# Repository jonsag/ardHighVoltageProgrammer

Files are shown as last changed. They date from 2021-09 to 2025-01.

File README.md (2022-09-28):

# ardHighVoltageProgrammer

## Links

[https://mightyohm.com/blog/products/hv-rescue-shield-2-x/](https://mightyohm.com/blog/products/hv-rescue-shield-2-x/)  

[https://www.instructables.com/HV-Rescue-Simple/](https://www.instructables.com/HV-Rescue-Simple/)  
[https://mightyohm.com/blog/2008/09/arduino-based-avr-high-voltage-programmer/](https://mightyohm.com/blog/2008/09/arduino-based-avr-high-voltage-programmer/)  
[https://microtherion.github.io/ScratchMonkey/HVPP.html](https://microtherion.github.io/ScratchMonkey/HVPP.html)  
[https://www.instructables.com/AVR-High-voltage-programming-Fuses-rescue/](https://www.instructables.com/AVR-High-voltage-programming-Fuses-rescue/)  
[http://denki.world3.net/avr_rescue.html](http://denki.world3.net/avr_rescue.html)  

[https://www.gmsystems.com/switching-reg-calculator-for-mc-34063-or-mc33063.html](https://www.gmsystems.com/switching-reg-calculator-for-mc-34063-or-mc33063.html)

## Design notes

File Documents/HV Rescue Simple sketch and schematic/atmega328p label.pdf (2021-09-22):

328$Arduino$pinout !$$$$A5

RX$A4
TX A3
2$$$$A2
3$$$$A1 4 $$$A0

V$$$$$$G
G$ARF
X1$AV
X2$13
5$$$$12
6$$$$11
7$$$$10
8$$$$$$9

328$pin$numbers !$$$$28

2$$$$27$
3$$$$26
4$$$$25
5$$$$24
6$$$$23
7$$$$22
8$$$$21
9$$$$20
10$$19
11$$18
12$$17
13$$16
14$$15

328$HV$pinout !$$$$

$$$$$
RDY$$$$
OE$BS

2
WR$$$7
BS1$$$$6
V$$$$$$$G
G$$$$ XTL1$$V

$$$$$$$$$$

5
XA0$$4
XA1$$3
PAG$$2 0$$$$$$$$1

328$HV$pinout$fat !$$$$$$$$$$$$$$$NC

$$$$$
RDY$$$$
OE$$$$$$$$$$BS

2
WR$$$$$$$$$$$$$7
BS1$$$$$$$$$$$$6
V$$$$$$$$$$$$$$$$$G
G$$$$
XTL1$$$$$$$$$$V
$$$$$$$$$$$$$$$$$$$$

5
XA0$$$$$$$$$$$$4
XA1$$$$$$$$$$$$3
PAG$$$$$$$$$$$$2
0$$$$$$$$$$$$$$$$$$1

328$ISP$target$pinout !$$$$NC

$$
$$
$$
$$
$$
V$$$$$$G
G$$
XTL AV
$$$SCK13

$$MISO12
$$MOSI11
$$
NC

328$ISP$target$pinout$fat !$$$$$$$$$$$$$$$$$$$$$NC

$$
$$
$$
$$
$$
V$$$$$$$$$$$$$$$$$$$$$$$G
G$$
XTL$$$$$$$$$$$$$$$$AV
$$$$$$$$$$$$$$$$$SCK13
$$$$$$$$$$$$$$MISO12
$$$$$$$$$$$$$MOSI11
$$
NC$$$$$$$$$$$$$$$$$NC$$$$$$$$$$$$$$$$$

HV$resistor$row$label

RDY
OE
WR
XTL1
BS2
BS1
XA0
XA1

## PAG 76543210

Nano$Arduino$pinout

13$$ $$$$$$$12
3V3$$$$$$$11$
ARF$$$$$$$10
A0$$$$$$$$$$$$9
A1$$$$$$$$$$$$8
A2$$$$$$$$$$$$7
A3$$$$$$$$$$$$6
A4$$$$$$$$$$$$5
A5$$$$$$$$$$$$4
A6$$$$$$$$$$$$3
A7$$$$$$$$$$$$2
VCC$$$GND
RST$$$$RST
GND$$$$$RX
VIN$$$$$$$TX

Nano$HV$programmer$
pinout

RDY$$

Vsup
$$$$$$$$$$$$$$OE
$$$$$$$$$$$$$WR
12VG$ BS2$$$
0$$$$$$$$$$XA0
BS1$$$$$$$$$$

7
XTL1$$$$$$$

6
XA1$$$$$$$$$

5
PAGEL$$$

4
$$$$$$$$$$$$$$$$$

3
$$$$$$$$$$$$$$$$$

2
VCC$$$GND

GND$$$$$$$$
VIN$$$$$$$$$$1

Nano$HV$programmer$ pinout$fat

RDY$$$$$$$$Vsup
$$$$$$$$$$$$$$$$$$$$OE
$$$$$$$$$$$$$$$$$$$WR
12VG$$$$$$$$BS2$$$
0$$$$$$$$$$$$$$$$XA0
BS1$$$$$$$$$$$$$$$$7
XTL1$$$$$$$$$$$$$6
XA1$$$$$$$$$$$$$$$5
PAGEL$$$$$$$$$$4
$$$$$$$$$$$$$$$$$$$$$$$

3
$$$$$$$$$$$$$$$$$$$$$$$

2
VCC$$$$$$$$$GND

GND$$$$$$$$$$$$$$
VIN$$$$$$$$$$$$$$$$1

Nano$ISP$programmer
pinout

13SCK$MISO12
3V3 MOSI11
ARF$$$$$

R10
A0$$$$$$$XTL

9
A1$$$$$$$$$$$$8
A2$$$$$$$$$$$$7
A3$$$$$$$$$$$$6
A4$$$$$$$$$$$$5
A5$$$$$$$$$$$$4
A6$$$$$$$$$$$$3
A7$$$$$$$$$$$$2
VCC$$$$$$$$$G
RST$$$$RST
GND$$$$$RX
VIN$$$$$$$TX

Nano$ISP$programmer
pinout$fat

13SCK$$$$$$$MISO12
3V3$$$$$$$$$$$ MOSI11
ARF$$$$$$$

RSTSEL10
A0$$$$$$$$$$$$$$$$$$$XTL

9
A1$$$$$$$$$$$$$$$$$$$$$$$$$$$8 A2$$$$$$$$$$$$$$$$$$$$$$$$$$$7 A3$$$$$$$$$$$$$$$$$$$$$$$$$$$6 A4$$$$$$$$$$$$$$$$$$$$$$$$$$$

5
A5$$$$$$$$$$$$$$$$$$$$$$$$$$$4 A6$$$$$$$$$$$$$$$$$$$$$$$$$$$3 A7$$$$$$$$$$$$$$$$$$$$$$$$$$$2 VCC$$$$$$$$$$$$$$$$$$$$$$$$G RST$$$$$$$$$$$$$$$$$$$RST
GND$$$$$$$$$$$$$$$$$$$$RX
VIN$$$$$$$$$$$$$$$$$$$$$$TX

Notes:$
Reset$pin is$pin$1$of$the$ ATmega328P target and$is$
marked$with$a$dot.$$
Use$datasheet$to$determine$ other$target$pinouts.
Label$text$can$be$printed$out$ and$use$double$sided$tape,$3M$ Post

[it$adhesive,$Xyron$Create

[
a

[Sticker$machine,$or$other$ methods$to$stick$to$
breadboard,$chip, or$Arduino.$$ Fat$pinouts$are$made$so$you$ can$slice$them$into$2$halves$ and$put$on$opposite$sides$of$ breadboard$instead$of$sticking$ them$to$the$top$of$Arduino$or$ chip.$
NC$means$no$connection$and$is$ included$in$some$pinouts$to$ help$line$up$the$sticker.
Wiring$to$Arduino$pin$number$ scheme$is$same$as$
HVRescue_Shield$2.12 except$ data$line$0$is$moved$from$RX$to$ A1,$which$was$occupied$by$the$ run$button$on HVRescue_Shield$ 2.12.$$
12V$gate$pin$on$A0$is$inverted,$ when$low$12V$is$applied$to$ target$Reset$line,$this$is$ opposite$of$HVRescue_Shield$ 2.12.$$
Font$is$Cambria$6$point in$Mac$ Word to$allow$for$alignment$ with$0.1$inch$pin$spacing.$$Print$ with$100%$scaling.

Pro$Mini$Arduino$pinout$

1$$$$$$$RAW
0$$$$$$$$GND$$$
RST$$$$RST
GND$$$VCC
2$$$$$$$$$$$$A3
3$$$$$$$$$$$$A2
4$$$$$$$$$$$$A1
5$$$$$$$$$$$$A0
6$$$$$$$$$$$$13
7$$$$$$$$$$$$12
8$$$$$$$$$$$$11
9$$$$$$$$$$$$10

Pro$Mini$HV$programmer$
pinout

1$$$$$$$$$RAW
$$$$$$$$$$$$GND

GND$$$VCC
2$$$$$$$XTL1$$$$$$$
3$$$$$$$$$$BS1
4$$$$$$$$$$$$$$$0
5$$$$$$$12VG
6$$$$$$$$$RDY
7$$$$$$$$Vsup
XA0$$$$$$OE
BS2$$$$$WR

A4=XA1
A5=PAGEL$$$$

Uno/Mega$Arduino$pinout$

AREF
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
Uno/Mega$HV$programmer

GND
RDY
Vsup
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
12VG
0
BS1
XTL1
XA1
PAGEL

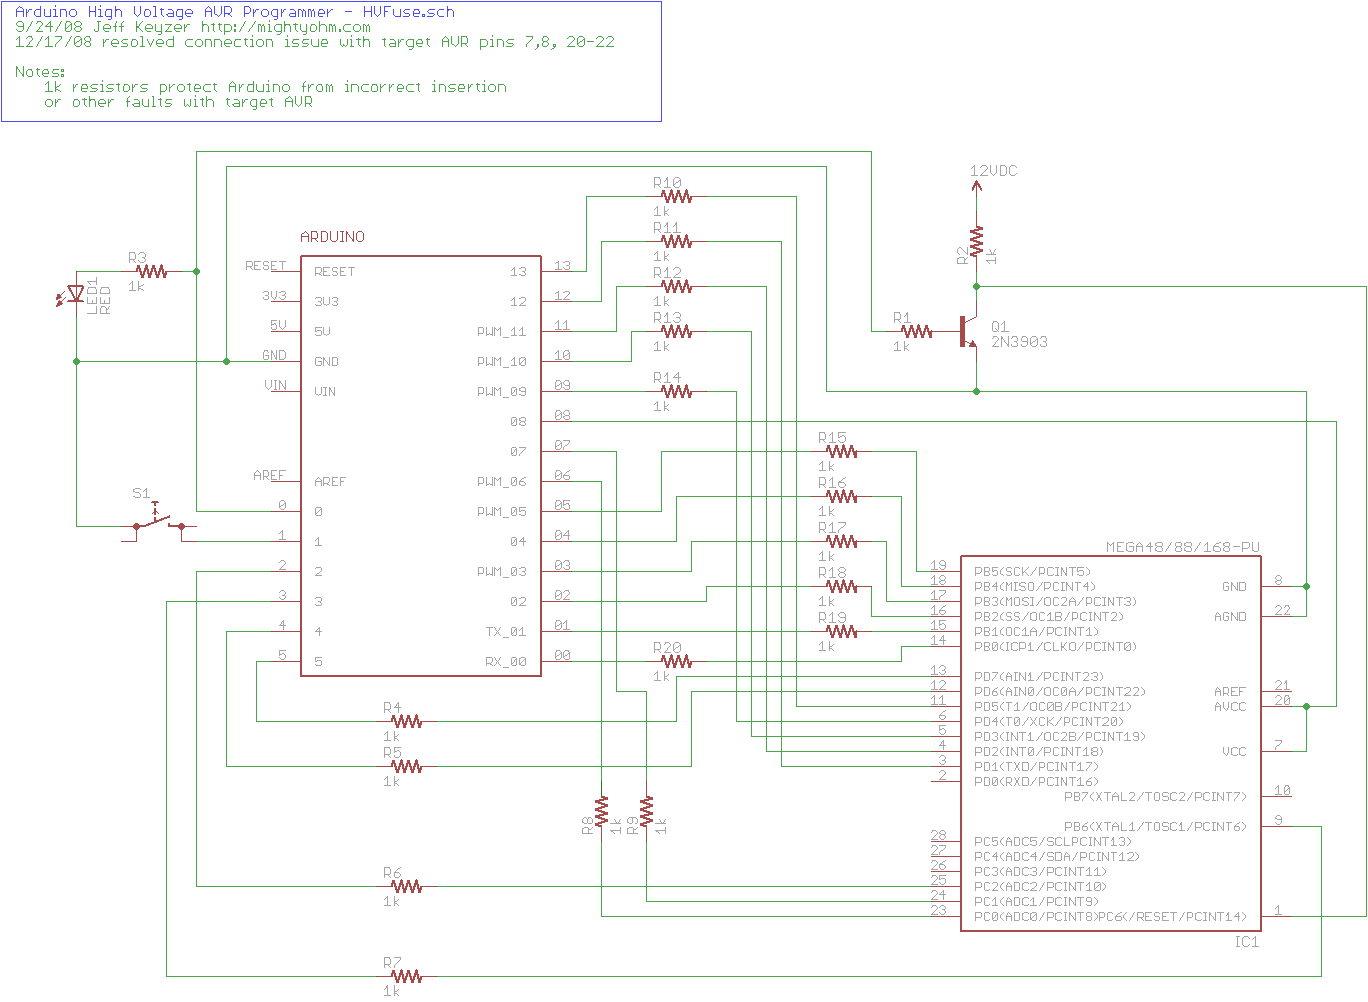
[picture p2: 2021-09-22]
Documents/hvfuse_fixed.png

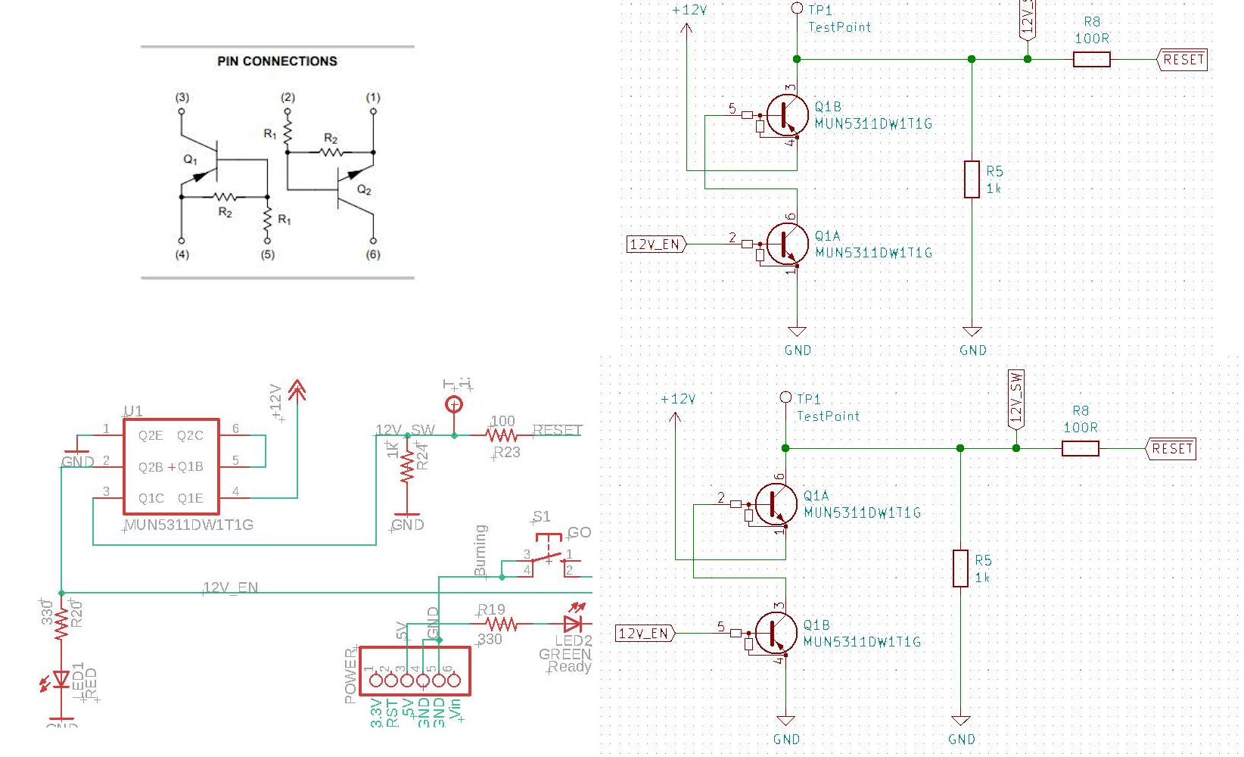
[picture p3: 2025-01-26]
Documents/mun5311....png

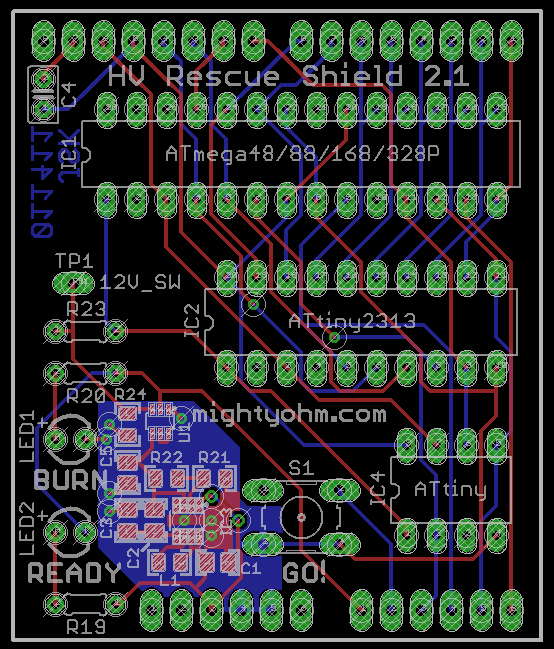
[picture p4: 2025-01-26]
Documents/AVR HV Rescue Shield 2/HVRescue_Shield_r21_layout.png

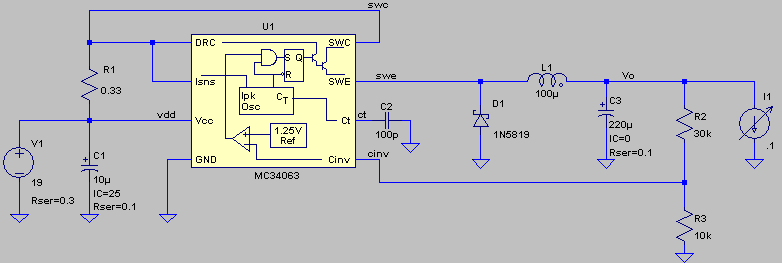
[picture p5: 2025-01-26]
Documents/mc-3-ltspice.png

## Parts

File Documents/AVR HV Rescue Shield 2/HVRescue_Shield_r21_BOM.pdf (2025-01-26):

Sheet1

AVR HV Rescue Shield
Bill of Materials
J. Keyzer
Item | Qty | Value | Description
1 | 1 PCB1 | NA | 2L FR4 1.8x2.1”
2 | 1IC3 | LT3464-TSOT | IC CONV BOOST MICROPWR TSOT23-8
3 | 1 U1 | MUN5311DW1T1G Complementary 50V NPN & PNP
4 | 1LED1 | RED | LED SS 3MM 625NM RED DIFF
5 | 1LED2 | GREEN | LED 3MM SHORT LENS GREEN TRANSP
6 | 1 R23 | | 100 RES 100 OHM 1/6W 5% CARBON FILM
7 | 2 R19,R20 | | 330 RES 330 OHM 1/6W 5% CARBON FILM
8 | 1 R20 | 1K | RES 1.0K OHM 1/6W 5% CARBON FILM
9 | 1 R24 | 1K | RES 1.00K OHM 1/8W 1% 0805 SMD
10 | 1 R21 | 137K | RES 137K OHM 1/8W 1% 0805 SMD
11 | 1 R22 | 1.21M | RES 1.21M OHM 1/8W 1% 0805 SMD
12 | 1 C2 | 0.22uF | CAP CER .22UF 50V X7R 0805
13 | 1 C3 | 0.47uF | CAP CER .47UF 25V X5R 0805
14 | 1 C1 | 1uF | CAP CER 1.0UF 10V X7R 0805
15 | 1L1 | 22uH | INDUCTOR 22UH 100MA 10% SMD
16 | 1IC1 | N/A | SOCKET IC OPEN FRAME 28POS .3"
17 | 1IC2 | N/A | SOCKET IC OPEN FRAME 20POS .3"
18 | 1IC4 | N/A | SOCKET IC OPEN FRAME 8POS .3"
19 | 1J1, J3, J2 | NA | SINGLE ROW HEADER, 1 X 40
20 | 1 S1 | GO | SWITCH TACT 6MM SPST H=5MM
21 | 1 C4 | DNP | not installed
22 | 1 C5 | DNP | not installed
23 | 1 TP1 | 12V_SW | test point

MightyOhm Engineering

Refdes

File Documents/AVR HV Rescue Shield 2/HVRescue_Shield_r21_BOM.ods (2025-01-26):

MightyOhm Engineering
AVR HV Rescue Shield
Bill of Materials
J. Keyzer
Item | Qty | Refdes | Value | Description
1 | 1 | PCB1 | NA | 2L FR4 1.8x2.1”
2 | 1 | IC3 | LT3464-TSOT | IC CONV BOOST MICROPWR TSOT23-8
3 | 1 | U1 | MUN5311DW1T1G | Complementary 50V NPN & PNP
4 | 1 | LED1 | RED | LED SS 3MM 625NM RED DIFF
5 | 1 | LED2 | GREEN | LED 3MM SHORT LENS GREEN TRANSP
6 | 1 | R23 | 100 | RES 100 OHM 1/6W 5% CARBON FILM
7 | 2 | R19,R20 | 330 | RES 330 OHM 1/6W 5% CARBON FILM
8 | 1 | R20 | 1K | RES 1.0K OHM 1/6W 5% CARBON FILM
9 | 1 | R24 | 1K | RES 1.00K OHM 1/8W 1% 0805 SMD
10 | 1 | R21 | 137K | RES 137K OHM 1/8W 1% 0805 SMD
11 | 1 | R22 | 1.21M | RES 1.21M OHM 1/8W 1% 0805 SMD
12 | 1 | C2 | 0.22uF | CAP CER .22UF 50V X7R 0805
13 | 1 | C3 | 0.47uF | CAP CER .47UF 25V X5R 0805
14 | 1 | C1 | 1uF | CAP CER 1.0UF 10V X7R 0805
15 | 1 | L1 | 22uH | INDUCTOR 22UH 100MA 10% SMD
16 | 1 | IC1 | N/A | SOCKET IC OPEN FRAME 28POS .3"
17 | 1 | IC2 | N/A | SOCKET IC OPEN FRAME 20POS .3"
18 | 1 | IC4 | N/A | SOCKET IC OPEN FRAME 8POS .3"
19 | 1 | J1, J3, J2 | NA | SINGLE ROW HEADER, 1 X 40
20 | 1 | S1 | GO | SWITCH TACT 6MM SPST H=5MM
21 | 1 | C4 | DNP | not installed
22 | 1 | C5 | DNP | not installed
23 | 1 | TP1 | 12V_SW | test point

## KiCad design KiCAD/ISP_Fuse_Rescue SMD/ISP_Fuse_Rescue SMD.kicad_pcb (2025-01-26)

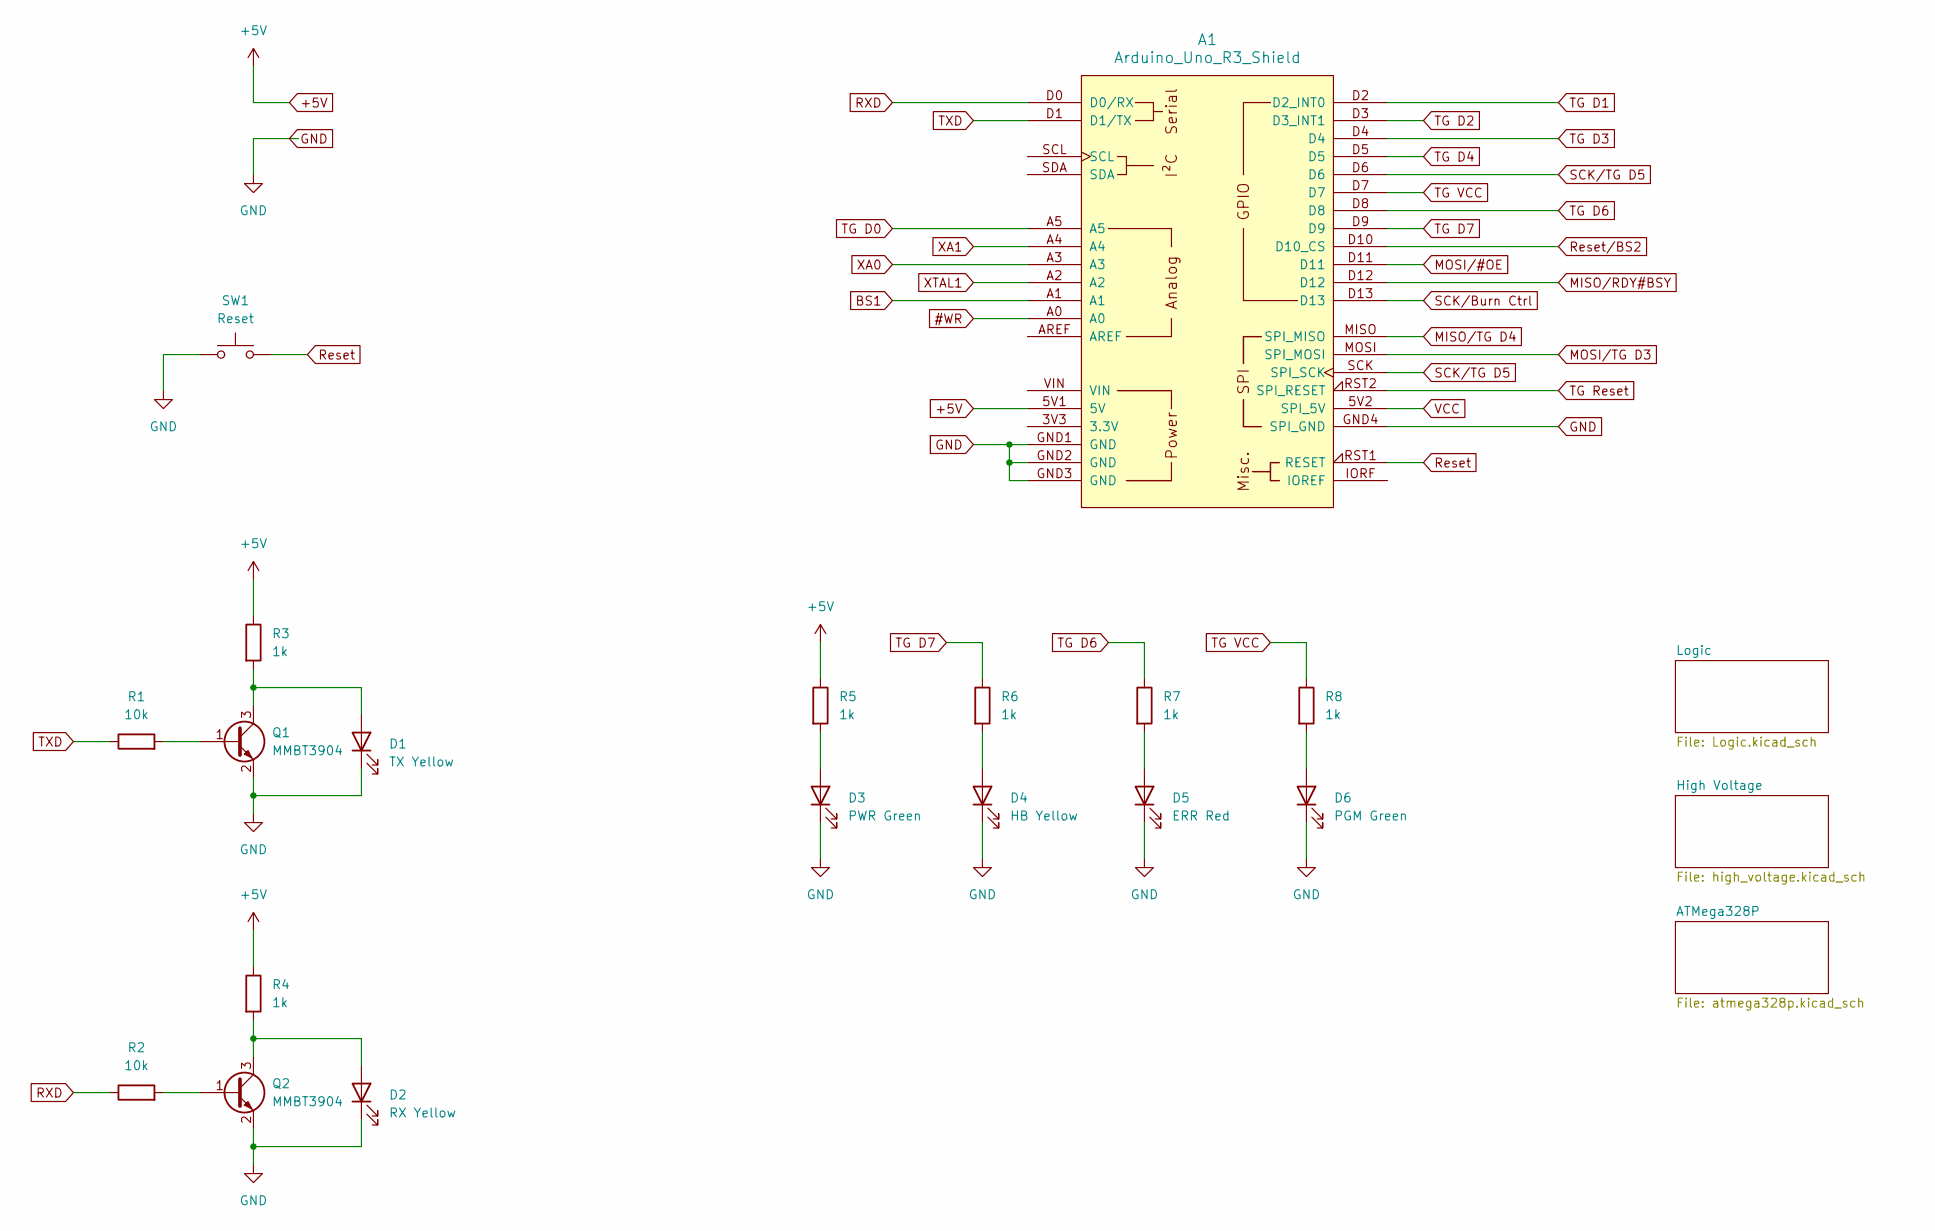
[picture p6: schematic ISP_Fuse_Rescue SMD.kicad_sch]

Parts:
A1: Arduino_Uno_R3_Shield; Arduino_UNO_R3_shield_incl ICSP_headers_large
D1: TX Yellow; LED_0805_2012Metric_Pad1.15x1.40mm_HandSolder
D2: RX Yellow; LED_0805_2012Metric_Pad1.15x1.40mm_HandSolder
D3: PWR Green; LED_0805_2012Metric_Pad1.15x1.40mm_HandSolder
D4: HB Yellow; LED_0805_2012Metric_Pad1.15x1.40mm_HandSolder
D5: ERR Red; LED_0805_2012Metric_Pad1.15x1.40mm_HandSolder
D6: PGM Green; LED_0805_2012Metric_Pad1.15x1.40mm_HandSolder
Q1, Q2: MMBT3904; SOT-23_Handsoldering
R1, R2: 10k; R_1206_3216Metric_Pad1.30x1.75mm_HandSolder
R3, R4, R5, R6, R7, R8: 1k; R_1206_3216Metric_Pad1.30x1.75mm_HandSolder
SW1: Reset; Switch tactile Omron B3S SMD

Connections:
#WR: A1.A0; also elsewhere on the board
+5V: A1.5V1 (5V), R3.1, R4.1, R5.1; also elsewhere on the board
BS1: A1.A1; also elsewhere on the board
GND: A1.GND1 (GND), A1.GND2 (GND), A1.GND3 (GND), A1.GND4 (SPI_GND), D1.1 (K), D2.1 (K), D3.1 (K), D4.1 (K), D5.1 (K), D6.1 (K), Q1.2 (E), Q2.2 (E), SW1.1; also elsewhere on the board
MISO/RDY#BSY: A1.D12; also elsewhere on the board
MISO/TG D4: A1.MISO (SPI_MISO); also elsewhere on the board
MOSI/#OE: A1.D11; also elsewhere on the board
MOSI/TG D3: A1.MOSI (SPI_MOSI); also elsewhere on the board
unnamed: D1.2 (A), Q1.3 (C), R3.2
unnamed: D2.2 (A), Q2.3 (C), R4.2
unnamed: D3.2 (A), R5.2
unnamed: D4.2 (A), R6.2
unnamed: D5.2 (A), R7.2
unnamed: D6.2 (A), R8.2
unnamed: Q1.1 (B), R1.2
unnamed: Q2.1 (B), R2.2
RXD: A1.D0 (D0/RX), R2.1
Reset: A1.RST1 (RESET), SW1.2
Reset/BS2: A1.D10 (D10_CS); also elsewhere on the board
SCK/Burn Ctrl: A1.D13; also elsewhere on the board
SCK/TG D5: A1.D6, A1.SCK (SPI_SCK); also elsewhere on the board
TG D0: A1.A5; also elsewhere on the board
TG D1: A1.D2 (D2_INT0); also elsewhere on the board
TG D2: A1.D3 (D3_INT1); also elsewhere on the board
TG D3: A1.D4; also elsewhere on the board
TG D4: A1.D5; also elsewhere on the board
TG D6: A1.D8, R7.1; also elsewhere on the board
TG D7: A1.D9, R6.1; also elsewhere on the board
TG Reset: A1.RST2 (SPI_RESET)
TG VCC: A1.D7, R8.1; also elsewhere on the board
TXD: A1.D1 (D1/TX), R1.1
VCC: A1.5V2 (SPI_5V)
XA1: A1.A4; also elsewhere on the board
XTAL1: A1.A2; also elsewhere on the board

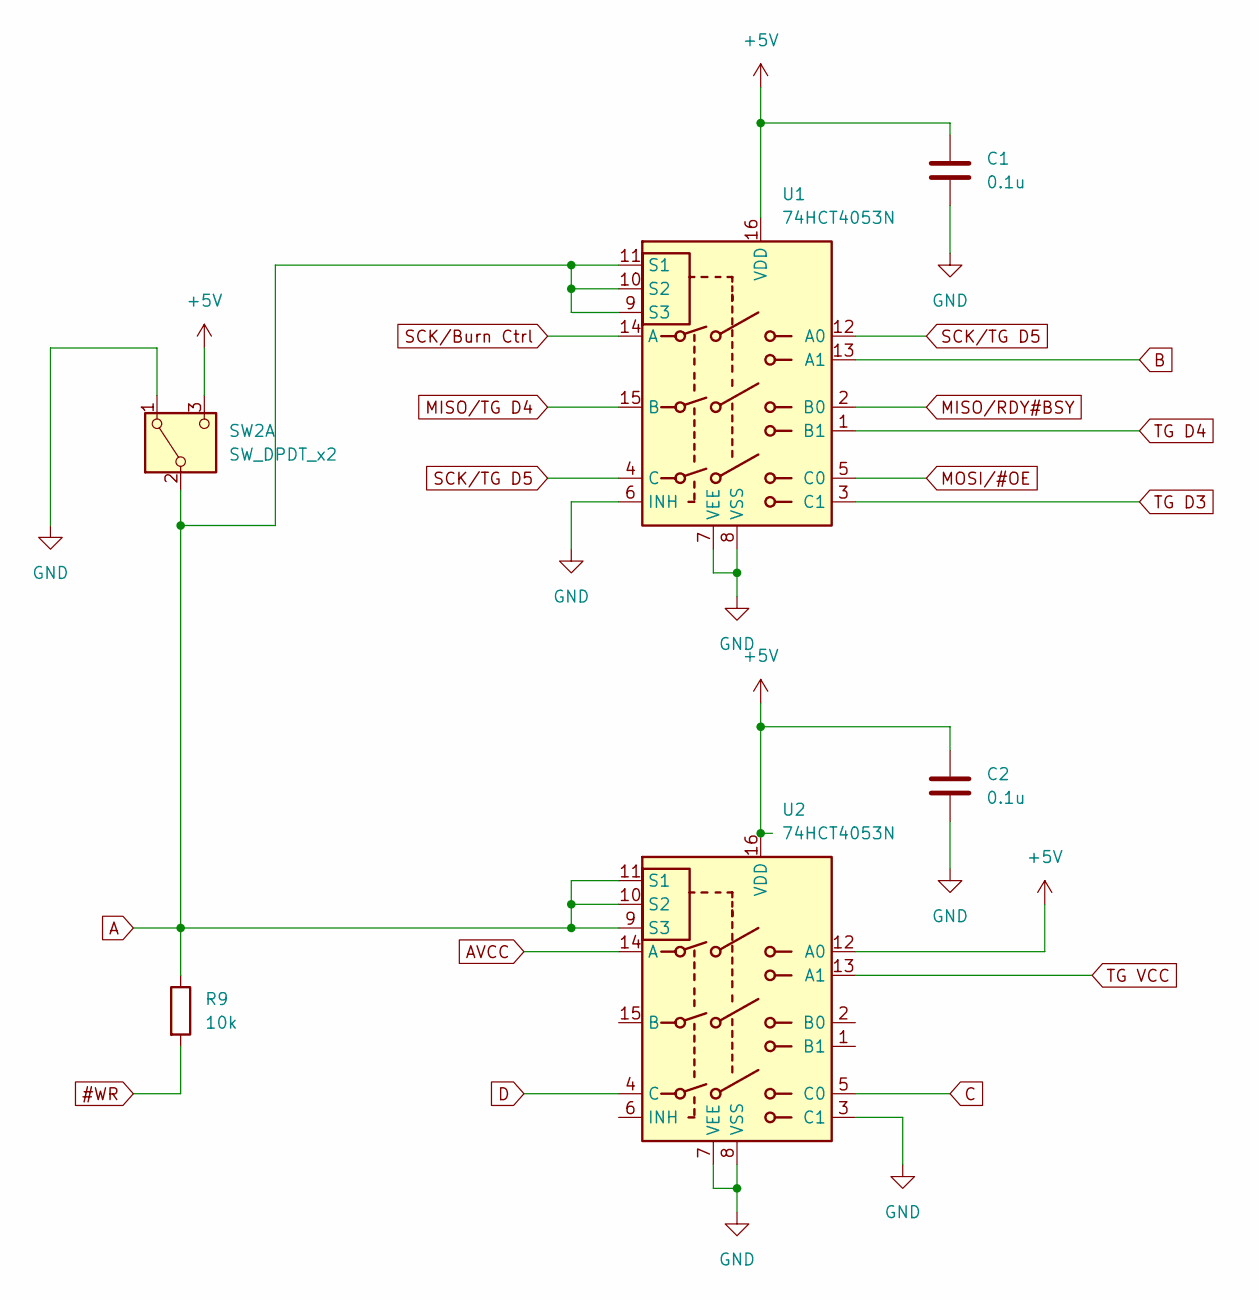
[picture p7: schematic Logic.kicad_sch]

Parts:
C1, C2: 0.1u; C_1206_3216Metric_Pad1.33x1.80mm_HandSolder
R9: 10k; R_1206_3216Metric_Pad1.30x1.75mm_HandSolder
SW2: SW_DPDT_x2; Switch slide 2-pole on-on
U1, U2: 74HCT4053N; SOIC-16_3.9x9.9mm_P1.27mm

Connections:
#WR: R9.2; also elsewhere on the board
+5V: C1.1, C2.1, SW2.3 (C), U1.16 (VDD), U2.12 (A0), U2.16 (VDD); also elsewhere on the board
A: R9.1, SW2.2 (B), U1.9 (S3), U1.10 (S2), U1.11 (S1), U2.9 (S3), U2.10 (S2), U2.11 (S1); also elsewhere on the board
AVCC: U2.14 (A); also elsewhere on the board
B: U1.13 (A1); also elsewhere on the board
C: U2.5 (C0); also elsewhere on the board
D: U2.4 (C); also elsewhere on the board
GND: C1.2, C2.2, SW2.1 (A), U1.6 (INH), U1.7 (VEE), U1.8 (VSS), U2.3 (C1), U2.7 (VEE), U2.8 (VSS); also elsewhere on the board
MISO/RDY#BSY: U1.2 (B0); also elsewhere on the board
MISO/TG D4: U1.15 (B); also elsewhere on the board
MOSI/#OE: U1.5 (C0); also elsewhere on the board
SCK/Burn Ctrl: U1.14 (A); also elsewhere on the board
SCK/TG D5: U1.4 (C), U1.12 (A0); also elsewhere on the board
TG D3: U1.3 (C1); also elsewhere on the board
TG D4: U1.1 (B1); also elsewhere on the board
TG VCC: U2.13 (A1); also elsewhere on the board

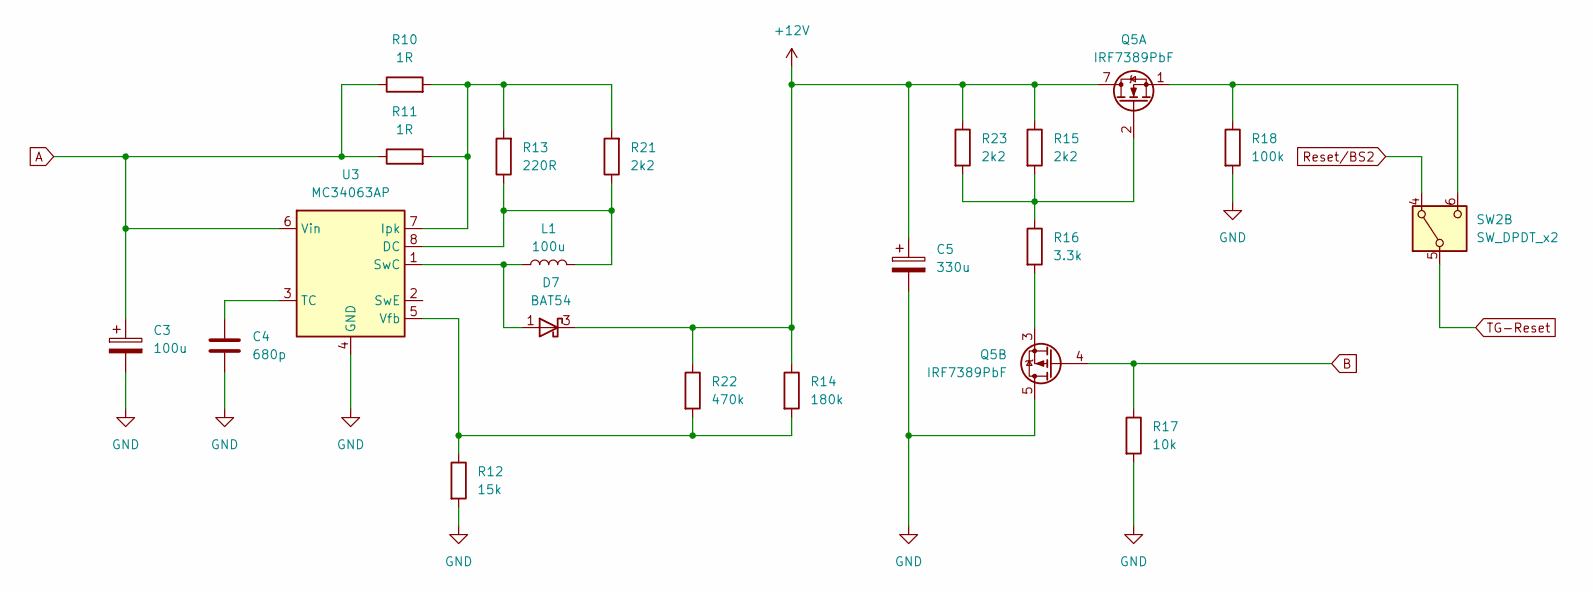
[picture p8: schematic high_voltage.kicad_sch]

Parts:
C3: 100u; CP_Elec_8x10
C4: 680p; C_1206_3216Metric_Pad1.33x1.80mm_HandSolder
C5: 330u; CP_Elec_10x10
D7: BAT54; SOT-23_Handsoldering
L1: 100u; L_1210_3225Metric_Pad1.42x2.65mm_HandSolder
Q5: IRF7389PbF; SOIC-8_3.9x4.9mm_P1.27mm
R10, R11: 1R; R_1206_3216Metric_Pad1.30x1.75mm_HandSolder
R12: 15k; R_1206_3216Metric_Pad1.30x1.75mm_HandSolder
R13: 220R; R_1206_3216Metric_Pad1.30x1.75mm_HandSolder
R14: 180k; R_1206_3216Metric_Pad1.30x1.75mm_HandSolder
R15, R21, R23: 2k2; R_1206_3216Metric_Pad1.30x1.75mm_HandSolder
R16: 3.3k; R_1206_3216Metric_Pad1.30x1.75mm_HandSolder
R17: 10k; R_1206_3216Metric_Pad1.30x1.75mm_HandSolder
R18: 100k; R_1206_3216Metric_Pad1.30x1.75mm_HandSolder
R22: 470k; R_1206_3216Metric_Pad1.30x1.75mm_HandSolder
SW2: SW_DPDT_x2; Switch slide 2-pole on-on
U3: MC34063AP; DIP-8_W7.62mm_Socket_w_dip_packet_LongPads

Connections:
+12V: C5.1, D7.3 (K), Q5.7 (D), Q5.8 (D), R14.1, R15.1, R22.1, R23.1
A: C3.1, R10.1, R11.1, U3.6 (Vin); also elsewhere on the board
B: Q5.4 (G), R17.1; also elsewhere on the board
GND: C3.2, C4.2, C5.2, Q5.5 (D), Q5.6 (D), R12.2, R17.2, R18.2, U3.4 (GND); also elsewhere on the board
unnamed: D7.1 (A), L1.1, U3.1 (SwC)
unnamed: Q5.2 (G), R15.2, R16.1, R23.2
unnamed: Q5.1 (S), R18.1, SW2.6 (C)
unnamed: Q5.3 (1), R16.2
unnamed: L1.2, R13.1, R21.1, U3.8 (DC)
unnamed: R10.2, R11.2, R13.2, R21.2, U3.7 (Ipk)
unnamed: C4.1, U3.3 (TC)
unnamed: R12.1, R14.2, R22.2, U3.5 (Vfb)
Reset/BS2: SW2.4 (A); also elsewhere on the board
TG-Reset: SW2.5 (B); also elsewhere on the board

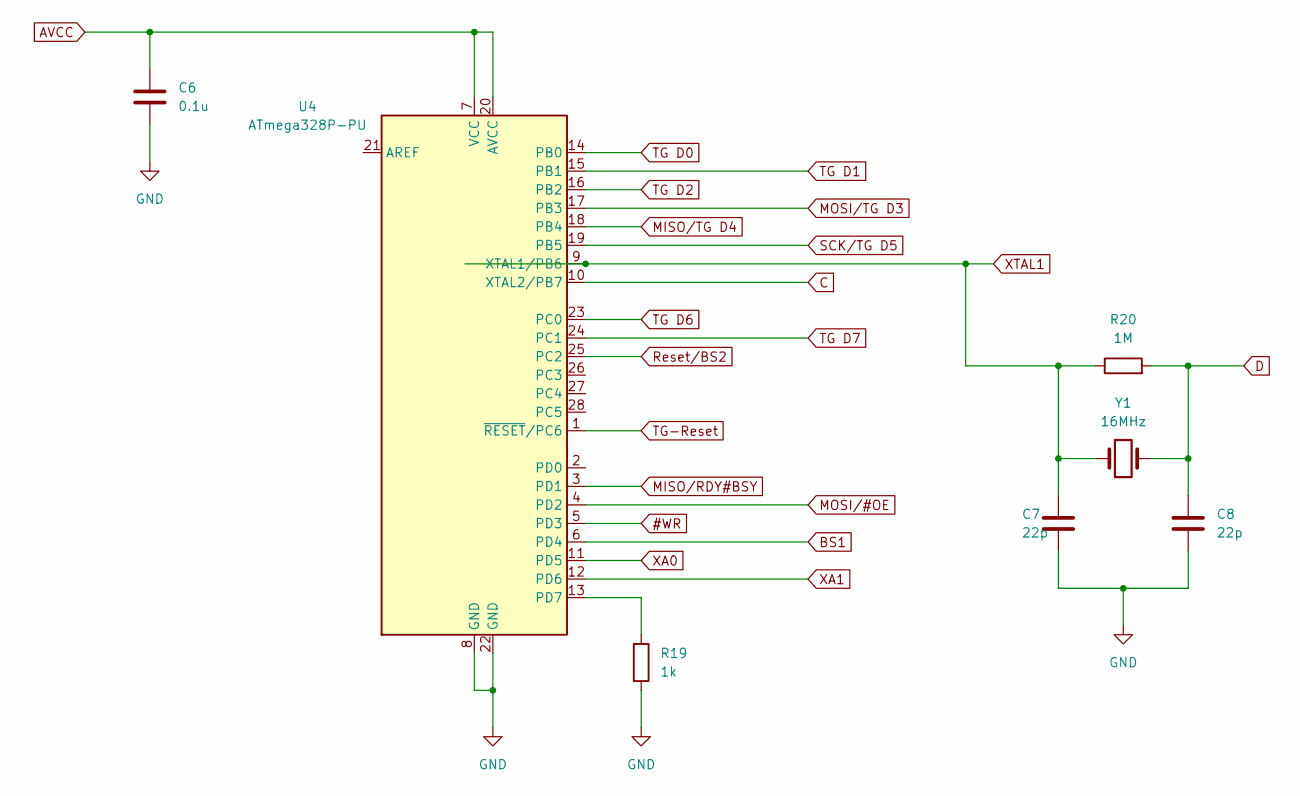
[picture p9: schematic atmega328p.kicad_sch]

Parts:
C6: 0.1u; C_1206_3216Metric_Pad1.33x1.80mm_HandSolder
C7, C8: 22p; C_1206_3216Metric_Pad1.33x1.80mm_HandSolder
R19: 1k; R_1206_3216Metric_Pad1.30x1.75mm_HandSolder
R20: 1M; R_1206_3216Metric_Pad1.30x1.75mm_HandSolder
U4: ATmega328P-PU; ZIF_DIP_Socket-28_W6.9_W7.62_W7.62_W12.7_W13.5_large
Y1: 16MHz; Crystal_HC49-4H_Vertical_large

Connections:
#WR: U4.5 (PD3); also elsewhere on the board
AVCC: C6.1, U4.7 (VCC), U4.20 (AVCC); also elsewhere on the board
BS1: U4.6 (PD4); also elsewhere on the board
C: U4.10 (XTAL2/PB7); also elsewhere on the board
D: C8.1, R20.2, Y1.2; also elsewhere on the board
GND: C6.2, C7.2, C8.2, R19.2, U4.8 (GND), U4.22 (GND); also elsewhere on the board
MISO/RDY#BSY: U4.3 (PD1); also elsewhere on the board
MISO/TG D4: U4.18 (PB4); also elsewhere on the board
MOSI/#OE: U4.4 (PD2); also elsewhere on the board
MOSI/TG D3: U4.17 (PB3); also elsewhere on the board
unnamed: R19.1, U4.13 (PD7)
Reset/BS2: U4.25 (PC2); also elsewhere on the board
SCK/TG D5: U4.19 (PB5); also elsewhere on the board
TG D0: U4.14 (PB0); also elsewhere on the board
TG D1: U4.15 (PB1); also elsewhere on the board
TG D2: U4.16 (PB2); also elsewhere on the board
TG D6: U4.23 (PC0); also elsewhere on the board
TG D7: U4.24 (PC1); also elsewhere on the board
TG-Reset: U4.1 (~RESET/PC6); also elsewhere on the board
XA0: U4.11 (PD5)
XA1: U4.12 (PD6); also elsewhere on the board
XTAL1: C7.1, R20.1, U4.9 (XTAL1/PB6), Y1.1; also elsewhere on the board

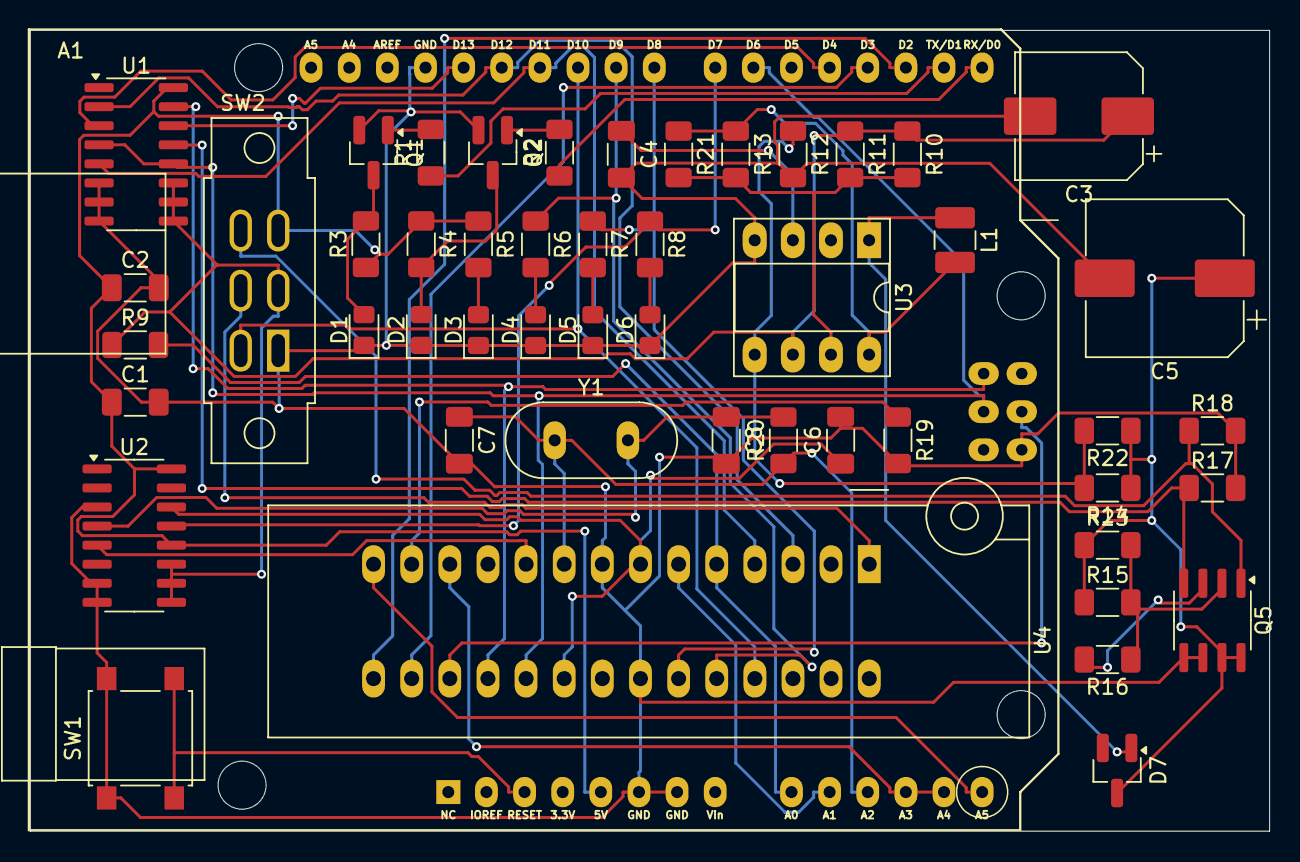
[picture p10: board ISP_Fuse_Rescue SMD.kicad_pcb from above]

Board: 2 copper layers, 82.6 x 53.3 mm, 50 parts (0 on the bottom side), 48 nets.

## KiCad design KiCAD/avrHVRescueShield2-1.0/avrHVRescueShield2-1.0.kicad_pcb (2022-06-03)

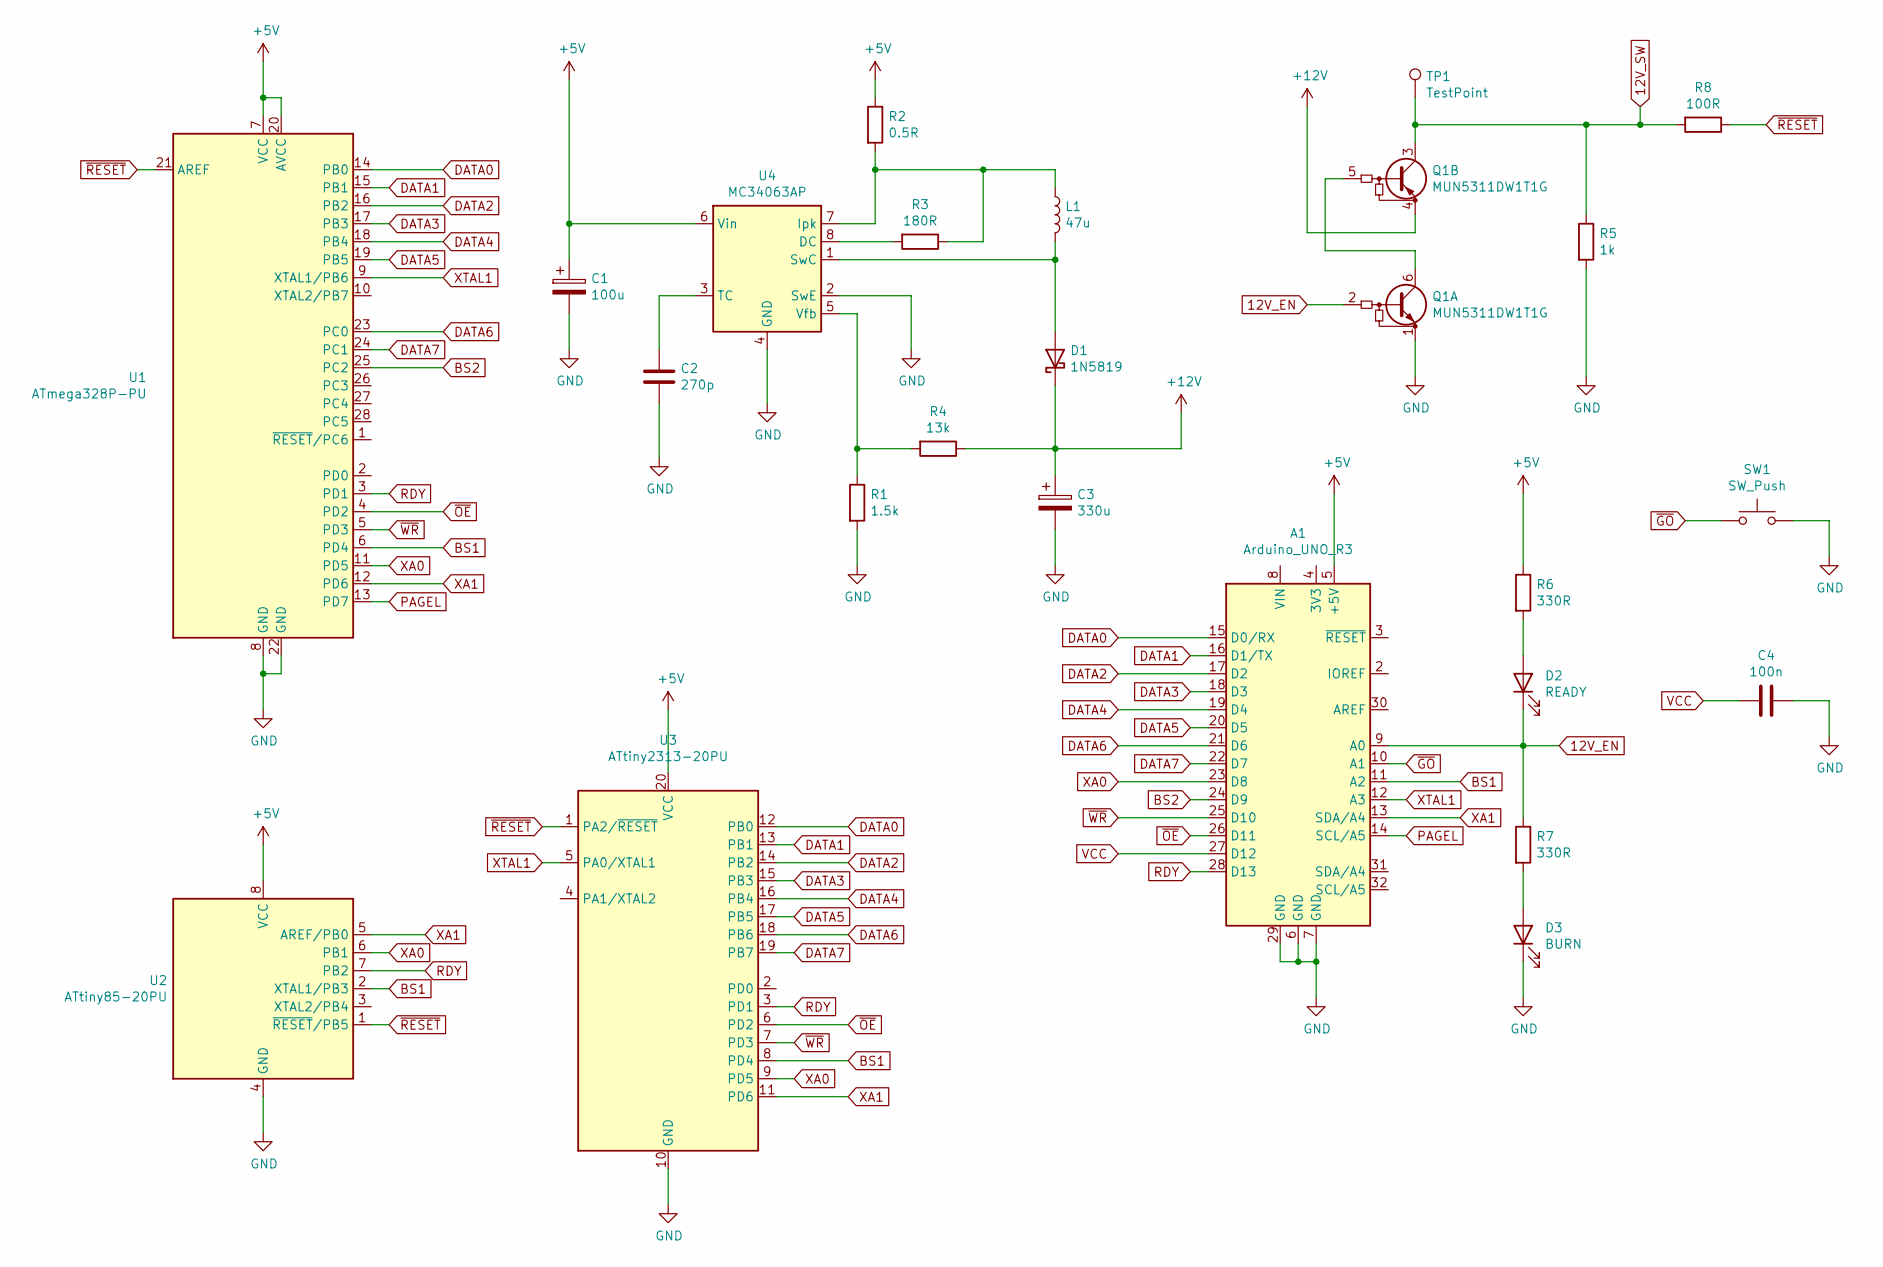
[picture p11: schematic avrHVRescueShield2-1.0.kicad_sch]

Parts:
A1: Arduino_UNO_R3; Arduino_UNO_R3_shield_large
C1: 100u; CP_Elec_8x10
C2: 270p; C_1206_3216Metric_Pad1.33x1.80mm_HandSolder
C3: 330u; CP_Elec_10x10
C4: 100n; C_1206_3216Metric_Pad1.33x1.80mm_HandSolder
D1: 1N5819; D_SMC_Handsoldering
D2: READY; LED_1206_3216Metric_Pad1.42x1.75mm_HandSolder
D3: BURN; LED_1206_3216Metric_Pad1.42x1.75mm_HandSolder
L1: 47u; L_1210_3225Metric_Pad1.42x2.65mm_HandSolder
Q1: MUN5311DW1T1G; SOT-363_SC-70-6_Handsoldering
R1: 1.5k; R_1206_3216Metric_Pad1.30x1.75mm_HandSolder
R2: 0.5R; R_1206_3216Metric_Pad1.30x1.75mm_HandSolder
R3: 180R; R_1206_3216Metric_Pad1.30x1.75mm_HandSolder
R4: 13k; R_1206_3216Metric_Pad1.30x1.75mm_HandSolder
R5: 1k; R_1206_3216Metric_Pad1.30x1.75mm_HandSolder
R6, R7: 330R; R_1206_3216Metric_Pad1.30x1.75mm_HandSolder
R8: 100R; R_1206_3216Metric_Pad1.30x1.75mm_HandSolder
SW1: SW_Push; SW_PUSH_6mm_large
TP1: TestPoint; Single_solder_pad
U1: ATmega328P-PU; DIP-28_W7.62mm_Socket_LongPads
U2: ATtiny85-20PU; DIP-8_W7.62mm_Socket_LongPads
U3: ATtiny2313-20PU; DIP-20_W7.62mm_Socket_LongPads
U4: MC34063AP; DIP-8_W7.62mm_Socket_w_dip_packet_LongPads

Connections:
12V_EN: A1.9 (A0), D2.1 (K), Q1.2 (B1), R7.1
12V_SW: Q1.3 (C1), R5.1, R8.2, TP1.1
+5V: A1.5 (+5V), C1.1, R2.1, R6.1, U1.7 (VCC), U1.20 (AVCC), U2.8 (VCC), U3.20 (VCC), U4.6 (Vin)
+12V: C3.1, D1.1 (K), Q1.4 (E1), R4.1
BS1: A1.11 (A2), U1.6 (PD4), U2.2 (XTAL1/PB3), U3.8 (PD4)
BS2: A1.24 (D9), U1.25 (PC2)
DATA0: A1.15 (D0/RX), U1.14 (PB0), U3.12 (PB0)
DATA1: A1.16 (D1/TX), U1.15 (PB1), U3.13 (PB1)
DATA2: A1.17 (D2), U1.16 (PB2), U3.14 (PB2)
DATA3: A1.18 (D3), U1.17 (PB3), U3.15 (PB3)
DATA4: A1.19 (D4), U1.18 (PB4), U3.16 (PB4)
DATA5: A1.20 (D5), U1.19 (PB5), U3.17 (PB5)
DATA6: A1.21 (D6), U1.23 (PC0), U3.18 (PB6)
DATA7: A1.22 (D7), U1.24 (PC1), U3.19 (PB7)
GND: A1.6 (GND), A1.7 (GND), A1.29 (GND), C1.2, C2.2, C3.2, C4.1, D3.1 (K), Q1.1 (E1), R1.2, R5.2, SW1.2, U1.8 (GND), U1.22 (GND), U2.4 (GND), U3.10 (GND), U4.2 (SwE), U4.4 (GND)
unnamed: C2.1, U4.3 (TC)
unnamed: D1.2 (A), L1.2, U4.1 (SwC)
unnamed: D2.2 (A), R6.2
unnamed: D3.2 (A), R7.2
unnamed: L1.1, R2.2, R3.1, U4.7 (Ipk)
unnamed: Q1.5 (B1), Q1.6 (C1)
unnamed: R1.1, R4.2, U4.5 (Vfb)
unnamed: R3.2, U4.8 (DC)
PAGEL: A1.14 (SCL/A5), U1.13 (PD7)
RDY: A1.28 (D13), U1.3 (PD1), U2.7 (PB2), U3.3 (PD1)
VCC: A1.27 (D12), C4.2
XA0: A1.23 (D8), U1.11 (PD5), U2.6 (PB1), U3.9 (PD5)
XA1: A1.13 (SDA/A4), U1.12 (PD6), U2.5 (AREF/PB0), U3.11 (PD6)
XTAL1: A1.12 (A3), U1.9 (XTAL1/PB6), U3.5 (PA0/XTAL1)
~GO: A1.10 (A1), SW1.1
~OE: A1.26 (D11), U1.4 (PD2), U3.6 (PD2)
~RESET: R8.1, U1.21 (AREF), U2.1 (~RESET/PB5), U3.1 (PA2/~RESET)
~WR: A1.25 (D10), U1.5 (PD3), U3.7 (PD3)

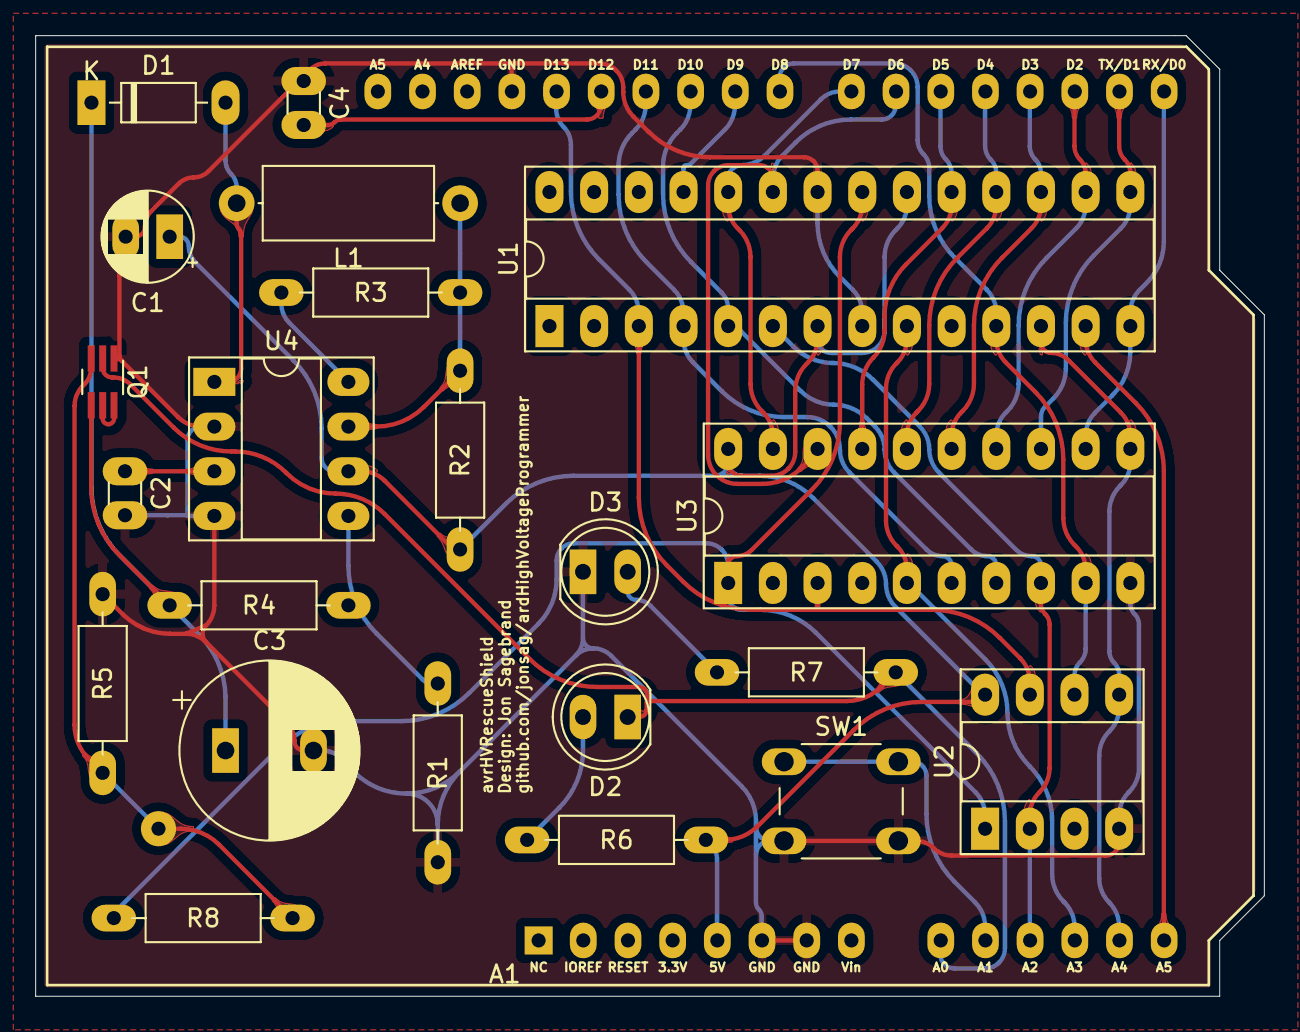
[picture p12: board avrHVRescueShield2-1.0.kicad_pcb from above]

Board: 2 copper layers, 69.8 x 54.6 mm, 24 parts (0 on the bottom side), 33 nets.

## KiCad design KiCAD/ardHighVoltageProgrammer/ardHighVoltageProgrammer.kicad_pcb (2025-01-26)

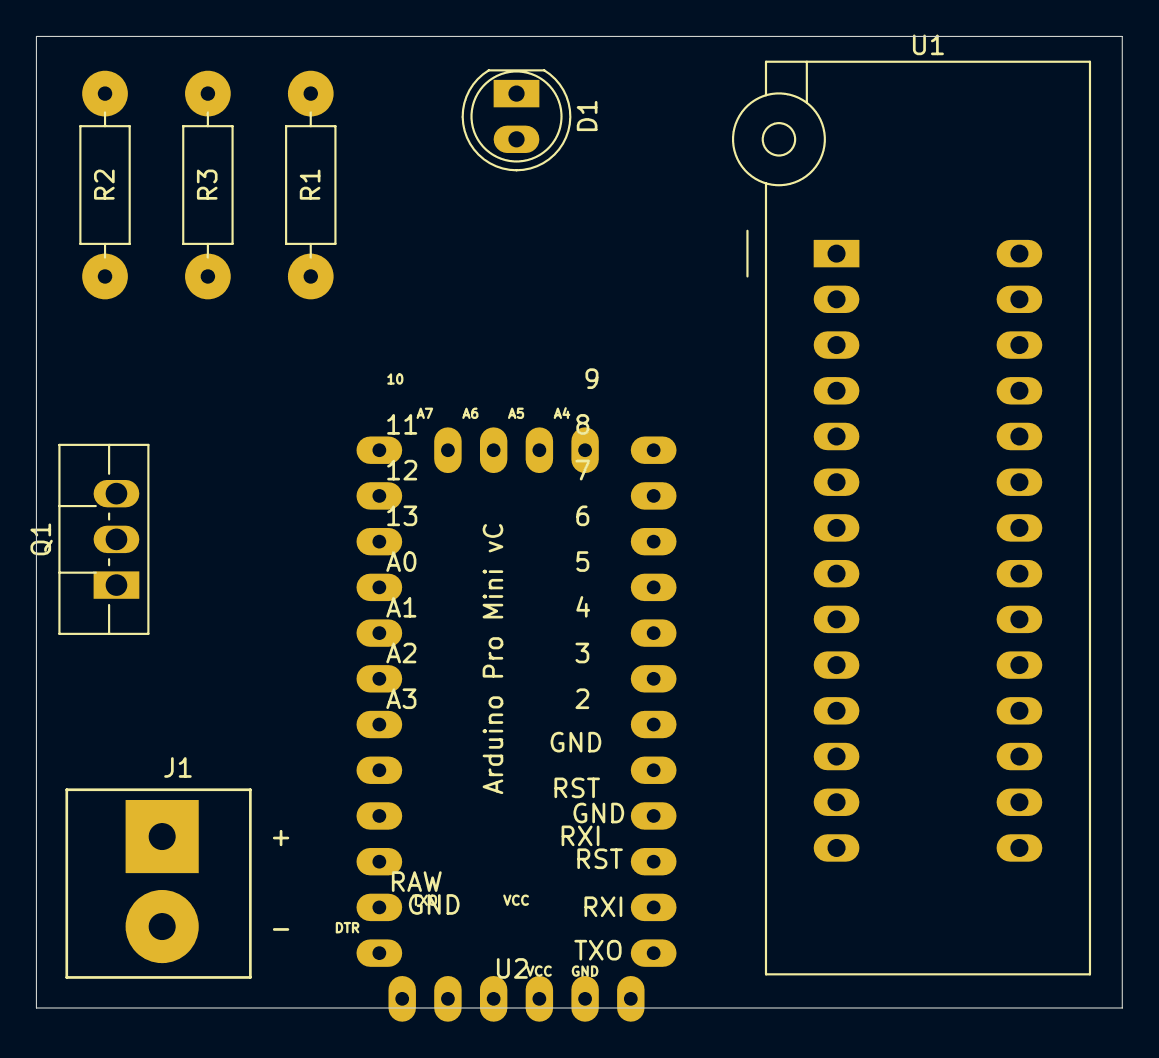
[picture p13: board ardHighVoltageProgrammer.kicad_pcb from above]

Board: 2 copper layers, 60.3 x 54.0 mm, 8 parts (0 on the bottom side), 24 nets, no tracks yet.

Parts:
D1: LED; LED_D5.0mm_larger_pads
J1: 2-pin_power_input_header; 2-pole_power_in_screw_terminal
Q1: 2N3904; TO-220F-3_Vertical_large
R1: 390R; R_Axial_DIN0207_L6.3mm_D2.5mm_P10.16mm_Horizontal_larger_pa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
R2, R3: 1k; R_Axial_DIN0207_L6.3mm_D2.5mm_P10.16mm_Horizontal_larger_pa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
U1: ATmega328P-PU; ZIF_DIP_Socket-28_W6.9_W7.62_W10.16_W12.7_W13.5_3M_228-4817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
U2: Arduino_Mini_Pro; Arduino_Pro_Mini_vC_larger_pads

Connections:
+5V: D1.2, U1.7, U1.20, U2.16
+12V: J1.1, R2.1
BS1: U1.6, U2.18
BS2: U1.25, U2.12
DATA0: U1.14, U2.19
DATA1: U1.15, U2.1
DATA2: U1.16, U2.5
DATA3: U1.17, U2.6
DATA4: U1.18, U2.7
DATA5: U1.19, U2.8
DATA6: U1.23, U2.9
DATA7: U1.24, U2.10
GND: J1.2, Q1.1, U1.8, U1.22, U2.14
unnamed: D1.1, R1.1
unnamed: Q1.2, R3.2
PAGEL: U1.13, U2.26
RDY: U1.3, U2.21
XA0: U1.11, U2.11
XA1: U1.12, U2.25
XTAL1: U1.9, U2.17
~OE: U1.4, U2.23
~RESET: Q1.3, R2.2, U1.1
~RST: R1.2, R3.1, U2.20
~WR: U1.5, U2.24

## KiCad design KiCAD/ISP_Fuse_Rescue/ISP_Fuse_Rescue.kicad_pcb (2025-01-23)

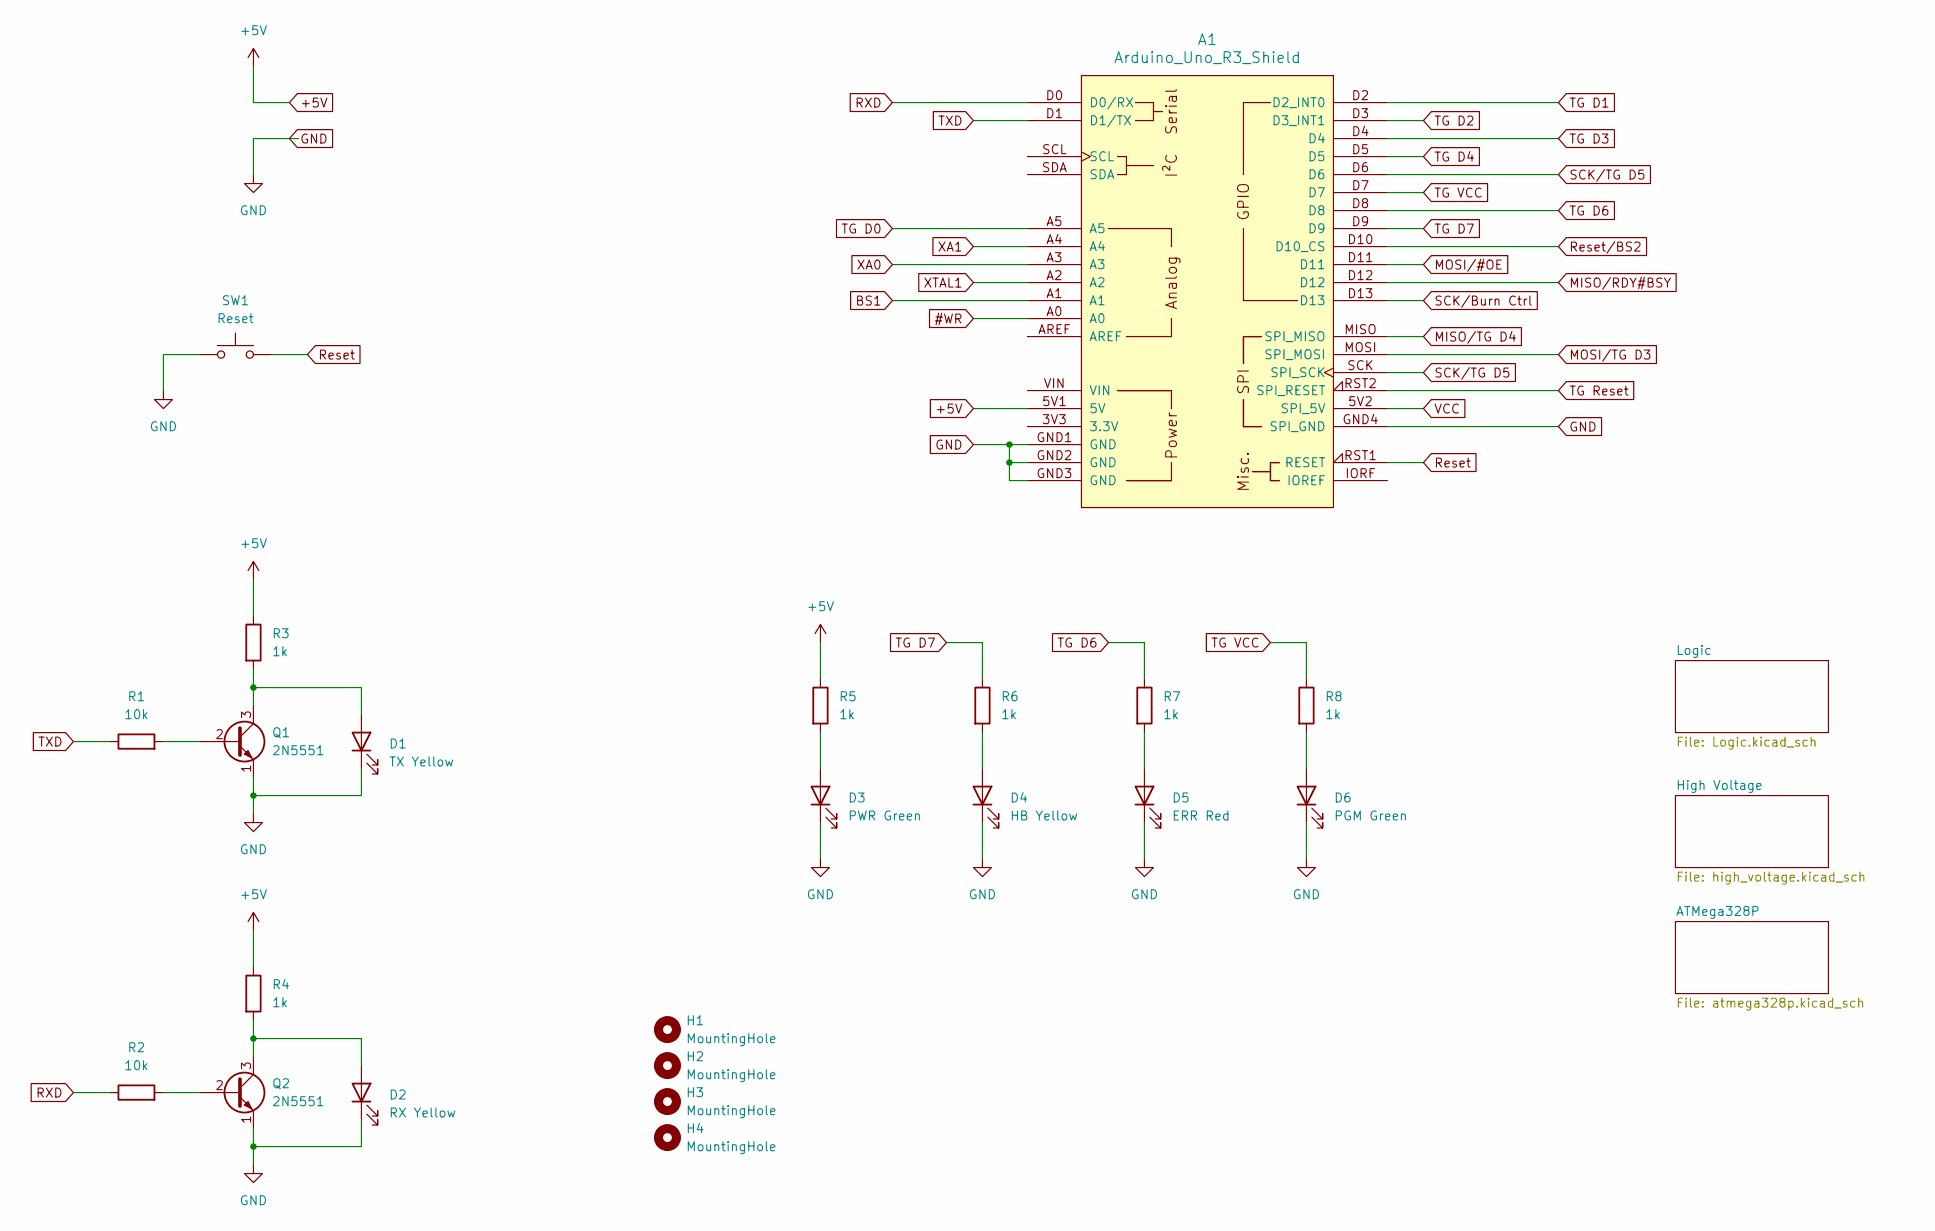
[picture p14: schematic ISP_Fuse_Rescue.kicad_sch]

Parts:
A1: Arduino_Uno_R3_Shield; Arduino_UNO_R3_shield_incl ICSP_headers_large
D1: TX Yellow; LED_D5.0mm_large
D2: RX Yellow; LED_D5.0mm_large
D3: PWR Green; LED_D5.0mm_large
D4: HB Yellow; LED_D5.0mm_large
D5: ERR Red; LED_D5.0mm_large
D6: PGM Green; LED_D5.0mm_large
H1, H2, H3, H4: MountingHole; MountingHole_3.2mm_M3
Q1, Q2: 2N5551; TO-92_Inline_Wide_large
R1, R2: 10k; R_Axial_DIN0207_L6.3mm_D2.5mm_P10.16mm_Horizontal_large
R3, R4, R5, R6, R7, R8: 1k; R_Axial_DIN0207_L6.3mm_D2.5mm_P10.16mm_Horizontal_large
SW1: Reset; SW_PUSH_6mm_large

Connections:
#WR: A1.A0; also elsewhere on the board
+5V: A1.5V1 (5V), R3.1, R4.1, R5.1; also elsewhere on the board
BS1: A1.A1; also elsewhere on the board
GND: A1.GND1 (GND), A1.GND2 (GND), A1.GND3 (GND), A1.GND4 (SPI_GND), D1.1 (K), D2.1 (K), D3.1 (K), D4.1 (K), D5.1 (K), D6.1 (K), Q1.1 (E), Q2.1 (E), SW1.1; also elsewhere on the board
MISO/RDY#BSY: A1.D12; also elsewhere on the board
MISO/TG D4: A1.MISO (SPI_MISO); also elsewhere on the board
MOSI/#OE: A1.D11; also elsewhere on the board
MOSI/TG D3: A1.MOSI (SPI_MOSI); also elsewhere on the board
unnamed: D1.2 (A), Q1.3 (C), R3.2
unnamed: D2.2 (A), Q2.3 (C), R4.2
unnamed: D3.2 (A), R5.2
unnamed: D4.2 (A), R6.2
unnamed: D5.2 (A), R7.2
unnamed: D6.2 (A), R8.2
unnamed: Q1.2 (B), R1.2
unnamed: Q2.2 (B), R2.2
RXD: A1.D0 (D0/RX), R2.1
Reset: A1.RST1 (RESET), SW1.2
Reset/BS2: A1.D10 (D10_CS); also elsewhere on the board
SCK/Burn Ctrl: A1.D13; also elsewhere on the board
SCK/TG D5: A1.D6, A1.SCK (SPI_SCK); also elsewhere on the board
TG D0: A1.A5; also elsewhere on the board
TG D1: A1.D2 (D2_INT0); also elsewhere on the board
TG D2: A1.D3 (D3_INT1); also elsewhere on the board
TG D3: A1.D4; also elsewhere on the board
TG D4: A1.D5; also elsewhere on the board
TG D6: A1.D8, R7.1; also elsewhere on the board
TG D7: A1.D9, R6.1; also elsewhere on the board
TG Reset: A1.RST2 (SPI_RESET)
TG VCC: A1.D7, R8.1; also elsewhere on the board
TXD: A1.D1 (D1/TX), R1.1
VCC: A1.5V2 (SPI_5V)
XA1: A1.A4; also elsewhere on the board
XTAL1: A1.A2; also elsewhere on the board

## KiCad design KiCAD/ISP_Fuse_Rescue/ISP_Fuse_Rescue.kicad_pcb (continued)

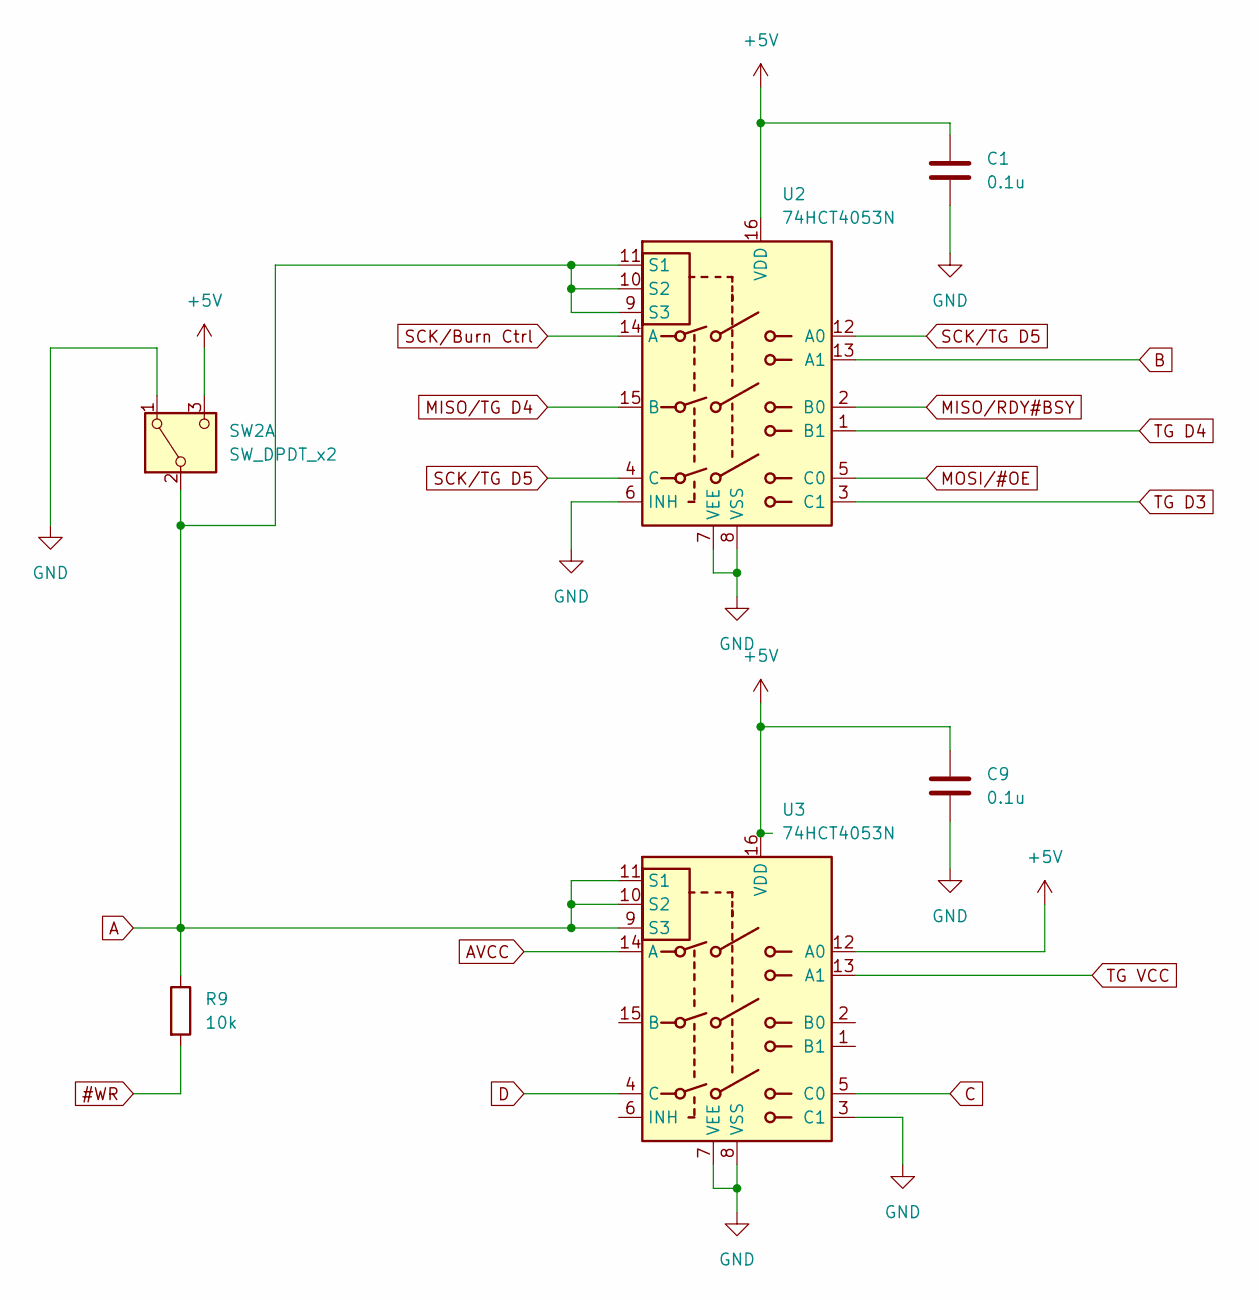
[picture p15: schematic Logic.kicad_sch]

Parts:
C1, C9: 0.1u; C_Disc_D3.0mm_W1.6mm_P2.50mm_larg
R9: 10k; R_Axial_DIN0207_L6.3mm_D2.5mm_P10.16mm_Horizontal_large
SW2: SW_DPDT_x2; Switch sub-miniatyr 2-pole on-on
U2, U3: 74HCT4053N; DIP-16_W7.62mm_LongPads w socket

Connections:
#WR: R9.2; also elsewhere on the board
+5V: C1.1, C9.1, SW2.3 (C), U2.16 (VDD), U3.12 (A0), U3.16 (VDD); also elsewhere on the board
A: R9.1, SW2.2 (B), U2.9 (S3), U2.10 (S2), U2.11 (S1), U3.9 (S3), U3.10 (S2), U3.11 (S1); also elsewhere on the board
AVCC: U3.14 (A); also elsewhere on the board
B: U2.13 (A1); also elsewhere on the board
C: U3.5 (C0); also elsewhere on the board
D: U3.4 (C); also elsewhere on the board
GND: C1.2, C9.2, SW2.1 (A), U2.6 (INH), U2.7 (VEE), U2.8 (VSS), U3.3 (C1), U3.7 (VEE), U3.8 (VSS); also elsewhere on the board
MISO/RDY#BSY: U2.2 (B0); also elsewhere on the board
MISO/TG D4: U2.15 (B); also elsewhere on the board
MOSI/#OE: U2.5 (C0); also elsewhere on the board
SCK/Burn Ctrl: U2.14 (A); also elsewhere on the board
SCK/TG D5: U2.4 (C), U2.12 (A0); also elsewhere on the board
TG D3: U2.3 (C1); also elsewhere on the board
TG D4: U2.1 (B1); also elsewhere on the board
TG VCC: U3.13 (A1); also elsewhere on the board

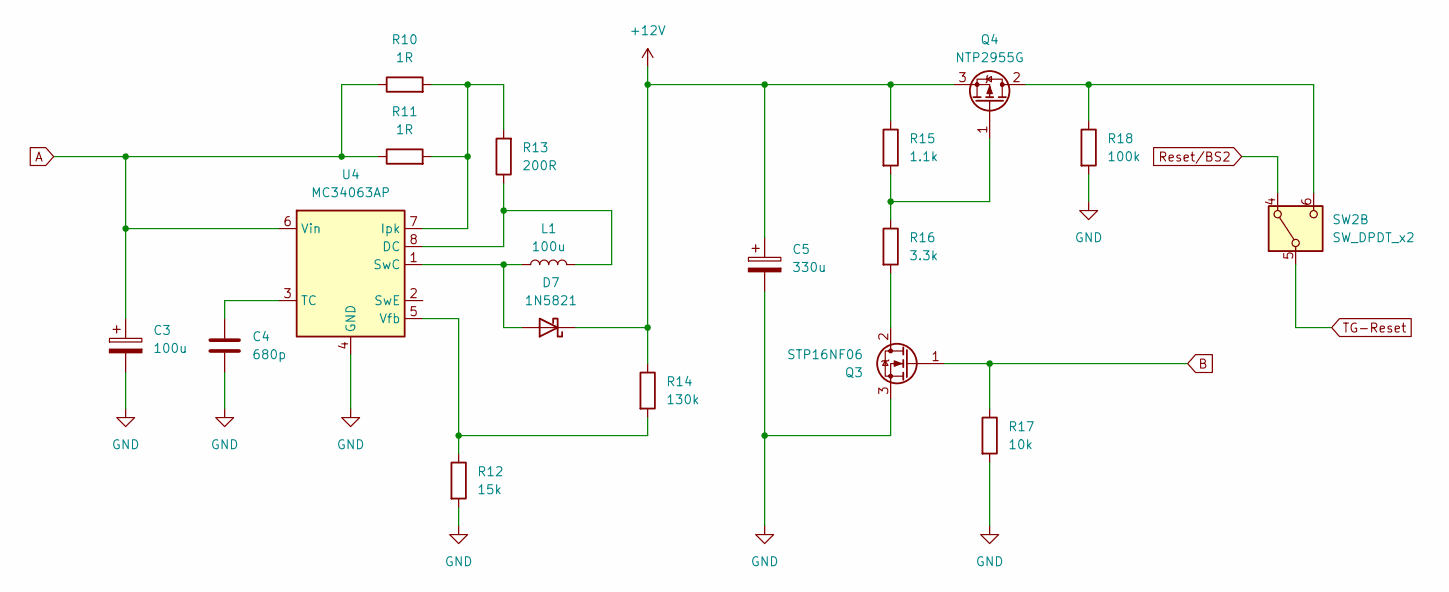
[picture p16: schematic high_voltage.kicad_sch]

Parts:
C3: 100u; CP_Radial_D5.0mm_P2.50mm_larger_pads
C4: 680p; C_Disc_D3.0mm_W1.6mm_P2.50mm_larg
C5: 330u; CP_Radial_D5.0mm_P2.50mm_larger_pads
D7: 1N5821; D_DO-201AD_P15.24mm_Horizontal
L1: 100u; L_Radial_D8.7mm_P5.00mm_Fastron_07HCP
Q3: STP16NF06; TO-220-3_Vertical_larger
Q4: NTP2955G; TO-220-3_Vertical_larger
R10, R11: 1R; R_Axial_DIN0207_L6.3mm_D2.5mm_P10.16mm_Horizontal_large
R12: 15k; R_Axial_DIN0207_L6.3mm_D2.5mm_P10.16mm_Horizontal_large
R13: 200R; R_Axial_DIN0207_L6.3mm_D2.5mm_P10.16mm_Horizontal_large
R14: 130k; R_Axial_DIN0207_L6.3mm_D2.5mm_P10.16mm_Horizontal_large
R15: 1.1k; R_Axial_DIN0207_L6.3mm_D2.5mm_P10.16mm_Horizontal_large
R16: 3.3k; R_Axial_DIN0207_L6.3mm_D2.5mm_P10.16mm_Horizontal_large
R17: 10k; R_Axial_DIN0207_L6.3mm_D2.5mm_P10.16mm_Horizontal_large
R18: 100k; R_Axial_DIN0207_L6.3mm_D2.5mm_P10.16mm_Horizontal_large
SW2: SW_DPDT_x2; Switch sub-miniatyr 2-pole on-on
U4: MC34063AP; DIP-8_W7.62mm_Socket_w_dip_packet_LongPads

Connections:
+12V: C5.1, D7.1 (K), Q4.3 (S), R14.1, R15.1
A: C3.1, R10.1, R11.1, U4.6 (Vin); also elsewhere on the board
B: Q3.1 (G), R17.1; also elsewhere on the board
GND: C3.2, C4.2, C5.2, Q3.3 (S), R12.2, R17.2, R18.2, U4.4 (GND); also elsewhere on the board
unnamed: D7.2 (A), L1.1, U4.1 (SwC)
unnamed: Q3.2 (D), R16.2
unnamed: Q4.2 (D), R18.1, SW2.6 (C)
unnamed: Q4.1 (G), R15.2, R16.1
unnamed: L1.2, R13.1, U4.8 (DC)
unnamed: R10.2, R11.2, R13.2, U4.7 (Ipk)
unnamed: C4.1, U4.3 (TC)
unnamed: R12.1, R14.2, U4.5 (Vfb)
Reset/BS2: SW2.4 (A); also elsewhere on the board
TG-Reset: SW2.5 (B); also elsewhere on the board

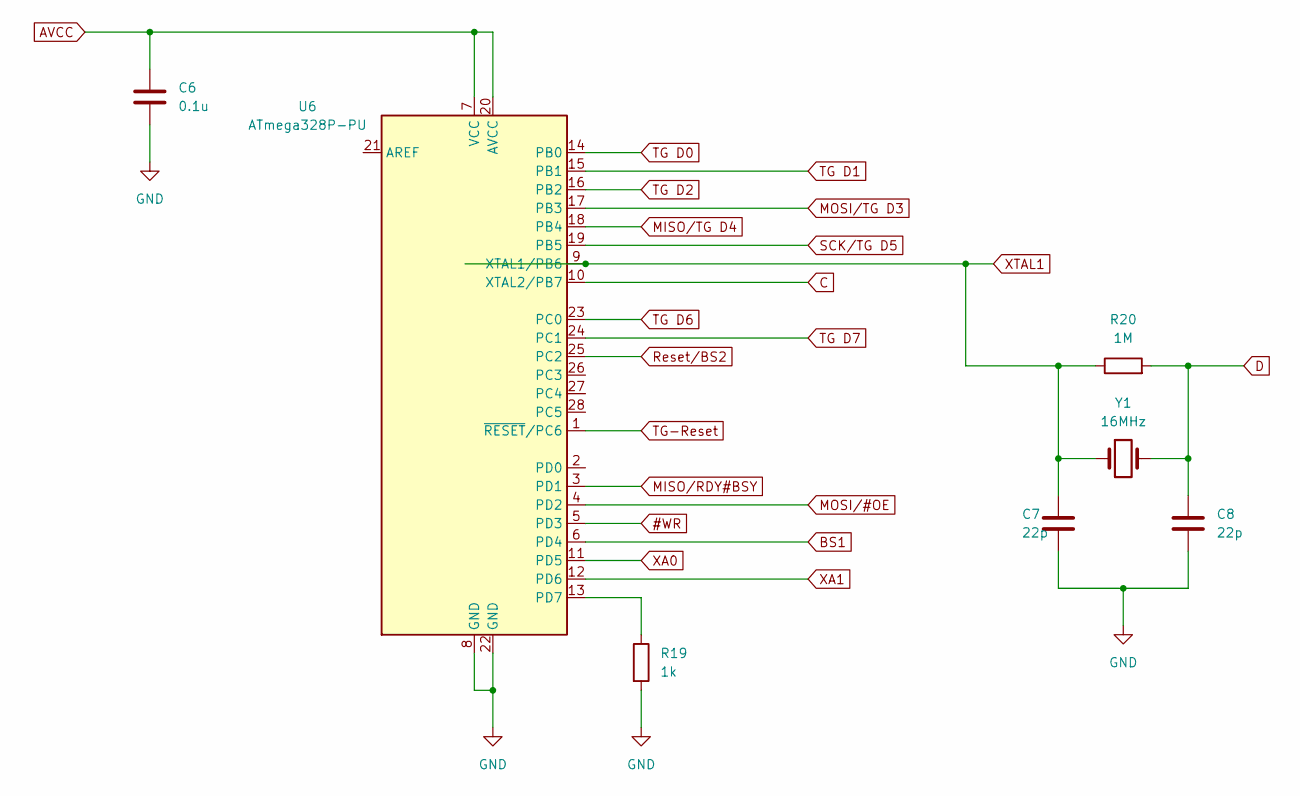
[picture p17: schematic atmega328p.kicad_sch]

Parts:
C6: 0.1u; CP_Radial_D5.0mm_P2.50mm_larger_pads
C7, C8: 22p; C_Disc_D3.0mm_W1.6mm_P2.50mm_larg
R19: 1k; R_Axial_DIN0207_L6.3mm_D2.5mm_P10.16mm_Horizontal_large
R20: 1M; R_Axial_DIN0207_L6.3mm_D2.5mm_P10.16mm_Horizontal_large
U6: ATmega328P-PU; ZIF_DIP_Socket-28_W6.9_W7.62_W7.62_W12.7_W13.5_large
Y1: 16MHz; Crystal_HC49-4H_Vertical_large

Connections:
#WR: U6.5 (PD3); also elsewhere on the board
AVCC: C6.1, U6.7 (VCC), U6.20 (AVCC); also elsewhere on the board
BS1: U6.6 (PD4); also elsewhere on the board
C: U6.10 (XTAL2/PB7); also elsewhere on the board
D: C8.1, R20.2, Y1.2; also elsewhere on the board
GND: C6.2, C7.2, C8.2, R19.2, U6.8 (GND), U6.22 (GND); also elsewhere on the board
MISO/RDY#BSY: U6.3 (PD1); also elsewhere on the board
MISO/TG D4: U6.18 (PB4); also elsewhere on the board
MOSI/#OE: U6.4 (PD2); also elsewhere on the board
MOSI/TG D3: U6.17 (PB3); also elsewhere on the board
unnamed: R19.1, U6.13 (PD7)
Reset/BS2: U6.25 (PC2); also elsewhere on the board
SCK/TG D5: U6.19 (PB5); also elsewhere on the board
TG D0: U6.14 (PB0); also elsewhere on the board
TG D1: U6.15 (PB1); also elsewhere on the board
TG D2: U6.16 (PB2); also elsewhere on the board
TG D6: U6.23 (PC0); also elsewhere on the board
TG D7: U6.24 (PC1); also elsewhere on the board
TG-Reset: U6.1 (~RESET/PC6); also elsewhere on the board
XA0: U6.11 (PD5)
XA1: U6.12 (PD6); also elsewhere on the board
XTAL1: C7.1, R20.1, U6.9 (XTAL1/PB6), Y1.1; also elsewhere on the board


Board: 2 copper layers, 98.4 x 74.9 mm, 52 parts (0 on the bottom side), 48 nets.

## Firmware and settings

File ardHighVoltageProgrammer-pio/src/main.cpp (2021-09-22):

#include "config.h"
#include "modules.h"
/*
HVRescue Simple 2015-09-17 suitable for breadboard
instructables.com/id/HV-Rescue-Simple
Modified from HVRescue_Shield Arduino sketch 3/15/11 2.12 for use with the HV Rescue Shield
by Jeff Keyzer  mightyohm.com/hvrescue2

Enhancements/mods by dmjlambert
HV control inverted to work with 12V battery switched
  with a transistor as in the older Jeff Keyzer sketch
  and common HV programmer sketches for ATtiny.
Changed baud rate to 115200
Moved data0 from D0 to A1 to keep from conflicting with serial port
  and to work better with boards such as CH340G Nano
Changed direct port manipulation of portD to indivial Arduino pins
Changed default fuse values to ATmega328P typical values
Removed run button
Removed ASKMODE
Briefly go into programming mode just for the task at hand
Accept a variety of number formats, hex, decimal, binary, upper/lower case
Made tolerant of any line ending for serial input or no line ending at all
Made compatible with most Arduinos such as Uno, Leonardo, Mega2560, 
  Pro Mini, Nano
Consolidated/simplified/organized into sections
Incorporated new user interface and menu with these commands:
1 2 3 set mode
L set low fuse value
H set high fuse value
X set ext fuse value
B or U set typical L H and X fuse values to factory blank 328 or Uno
W write fuses
R read fuses
? or any invalid character display info
Attempted to preserve non-interactive setting.  Although the sketch
ends up at an interactive menu prompt, the work it does before getting
to the interactive state can be used.  Plug in a target chip and press
the Arduino reset button to program or read the chip fuses, then unplug
the chip and plug in another and reset to repeat.

The HVPP routines are based on those described in the ATmega48/88/168 datasheet rev.
2545M-AVR-09/07, pg. 290-297 and the ATtiny2313 datasheet rev. 2543I-AVR-04/06 pg. 165-176.

The HVSP routines are based on the ATtiny25/45/85 and 13A datasheets (ATtiny25/45/85 2586M–AVR–07/10 pg. 159-165,
ATtiny13A 8126E-AVR-7/10 pg. 109-116).

GNU General Public License gnu.org/licenses
*/

void setup()
{ // run once, when the sketch starts
  // reserve bytes for the inputString
  inputString.reserve(26);

  // Set up control lines for HV parallel programming

  // clear digital pins 0-7
  digitalWrite(DATA0, 0);
  digitalWrite(DATA1, 0);
  digitalWrite(DATA2, 0);
  digitalWrite(DATA3, 0);
  digitalWrite(DATA4, 0);
  digitalWrite(DATA5, 0);
  digitalWrite(DATA6, 0);
  digitalWrite(DATA7, 0);

  //  set digital pins 0-7 as inputs for now
  pinMode(DATA0, INPUT);
  pinMode(DATA1, INPUT);
  pinMode(DATA2, INPUT);
  pinMode(DATA3, INPUT);
  pinMode(DATA4, INPUT);
  pinMode(DATA5, INPUT);
  pinMode(DATA6, INPUT);
  pinMode(DATA7, INPUT);

  pinMode(VCC, OUTPUT);
  pinMode(RDY, INPUT);
  pinMode(OE, OUTPUT);
  pinMode(WR, OUTPUT);
  pinMode(BS1, OUTPUT);
  pinMode(XA0, OUTPUT);
  pinMode(XA1, OUTPUT);
  pinMode(PAGEL, OUTPUT);
  pinMode(RST, OUTPUT); // enable signal for DC-DC converter that generates +12V !RESET
  pinMode(BS2, OUTPUT);
  pinMode(XTAL1, OUTPUT);

  // Initialize output pins as needed
  digitalWrite(RST, HIGH); // Turn off 12V step-up converter (non-inverting, unlike original circuit)
  digitalWrite(VCC, LOW);

  Serial.begin(BAUD); // Open serial port
  delay(50);
#if defined __AVR_ATmega32U4__ && INTERACTIVE == 1
  // if Leonardo or similar wait for serial monitor connection
  while (!Serial)
    ;
#endif
  Serial.println(F("\n\nReset\n"));
  Serial.println(F(__FILE__));
  Serial.println();

} // end of setup

void loop()
{ // run over and over again

  byte read_hfuse, read_lfuse, read_efuse; // fuses read from target for verify
  // variable to store what to do next, options
  // 0=display choices
  // 1=prompt for a command
  // 2=do nothing and expect further input
  // 3=read fuses from target AVR
  // 4=write fuses to target AVR
  static int doNext = 0;
#if (INTERACTIVE == 0)
  if (doNext == 0)
  {
    doNext = 4; //non-interactive, just write the fuses, change to 3 to just read the fuses
  }
#endif

  if (doNext == 0)
  { // 0=display choices
    Serial.print("Selected mode: ");
    switch (mode)
    {
    case ATMEGA:
      Serial.println("ATMEGA");
      break;
    case TINY2313:
      Serial.println("ATtiny2313");
      break;
    case HVSP:
      Serial.println("ATtiny/HVSP");
      break;
    }
    Serial.println(F("Typical fuse values:"));
    Serial.println(F("          blank ATmega328P    UNO     Duemilanove328"));
    Serial.println(F("                    L 0x62   L 0xFF   L 0xFF"));
    Serial.println(F("                    H 0xD9   H 0xDE   H 0xDA"));
    Serial.println(F("                    X 0xFF   X 0xFD   X 0xFD"));
    Serial.print(F("\nProposed Low Fuse  "));
    Serial.print(F("hex: "));
    printHex(lfuse);
    Serial.print(F("  bin: "));
    printBits(lfuse);
    Serial.println();
    Serial.print(F("Proposed High Fuse "));
    Serial.print(F("hex: "));
    printHex(hfuse);
    Serial.print(F("  bin: "));
    printBits(hfuse);
    Serial.println();
    Serial.print(F("Proposed Ext Fuse  "));
    Serial.print(F("hex: "));
    printHex(efuse);
    Serial.print(F("  bin: "));
    printBits(efuse);
    Serial.println();
    Serial.println(F("\nCommands:"));
    Serial.println(F("1 select mode ATmegaXX8 28-pin"));
    Serial.println(F("2 select mode ATtiny2313"));
    Serial.println(F("3 select mode ATtiny 8-pin / HVSP"));
    Serial.println(F("L, H, or X followed by a number changes the proposed fuse"));
    Serial.println(F("B or U changes the proposed fuses to Blank or Uno"));
    Serial.println(F("R reads the current fuses from the target AVR"));
    Serial.println(F("W writes the proposed fuses to the target AVR"));
    Serial.println(F("Number format accepted is hex in the form FF or 0xFF"));
    Serial.println(F("    or decimal in the form NUM255"));
    Serial.println(F("    or binary in the form BIN11111111"));
    Serial.println(F("Upper or lower case is acceptable"));
    doNext = 1;
  }
  if (doNext == 1)
  { // 1=prompt for a command
    Serial.println(F("\nEnter a command:"));
    doNext = 2;
  }
  // 2=do nothing and expect further input, no routine for it, just skip through the loop

  if (doNext == 3)
  { // 3=read fuses from target AVR
    Serial.end();
    delay(50);
    // Initialize pins to enter programming mode

    // clear digital pins 0-7
    digitalWrite(DATA0, 0);
    digitalWrite(DATA1, 0);
    digitalWrite(DATA2, 0);
    digitalWrite(DATA3, 0);
    digitalWrite(DATA4, 0);
    digitalWrite(DATA5, 0);
    digitalWrite(DATA6, 0);
    digitalWrite(DATA7, 0);

    // set digital pins 0-7 as inputs for now
    pinMode(DATA0, INPUT);
    pinMode(DATA1, INPUT);
    pinMode(DATA2, INPUT);
    pinMode(DATA3, INPUT);
    pinMode(DATA4, INPUT);
    pinMode(DATA5, INPUT);
    pinMode(DATA6, INPUT);
    pinMode(DATA7, INPUT);

    digitalWrite(PAGEL, LOW);
    digitalWrite(XA1, LOW);
    digitalWrite(XA0, LOW);
    digitalWrite(BS1, LOW);
    digitalWrite(BS2, LOW);
    digitalWrite(WR, LOW); // ATtiny2313 needs this to be low to enter programming mode, ATmega doesn't care
    digitalWrite(OE, LOW);

    if (mode == HVSP)
    {
      digitalWrite(SDI, LOW); // set necessary pin values to enter programming mode
      digitalWrite(SII, LOW);
      pinMode(SDO, OUTPUT);   // SDO is same as RDY pin
      digitalWrite(SDO, LOW); // needs to be low to enter programming mode
    }

    // Enter programming mode
    digitalWrite(VCC, HIGH); // Apply VCC to start programming process
    delayMicroseconds(80);
    digitalWrite(RST, LOW); // Apply 12V to !RESET thru transistor

    if (mode == HVSP)
    {
      // reset SDO after short delay, longer leads to logic contention because target sets SDO high after entering programming mode
      delayMicroseconds(1); // datasheet says 10us, 1us is needed to avoid drive contention on SDO
      pinMode(SDO, INPUT);  // set to input to avoid logic contention
    }

    delayMicroseconds(10); // Give lots of time for part to enter programming mode
    digitalWrite(OE, HIGH);
    digitalWrite(WR, HIGH); // Now that we're in programming mode we can disable !WR
    delay(1);

    // Now in programming mode until RST is set HIGH again to remove 12V

    if (mode == HVSP)
    {
      HVSP_read(HVSP_READ_LFUSE_DATA, HVSP_READ_LFUSE_INSTR1);
      HVSP_read(0x00, HVSP_READ_LFUSE_INSTR2);
      read_lfuse = HVSP_read(0x00, HVSP_READ_LFUSE_INSTR3);

      HVSP_read(HVSP_READ_HFUSE_DATA, HVSP_READ_HFUSE_INSTR1);
      HVSP_read(0x00, HVSP_READ_HFUSE_INSTR2);
      read_hfuse = HVSP_read(0x00, HVSP_READ_HFUSE_INSTR3);

#if (BURN_EFUSE == 1)
      HVSP_read(HVSP_READ_EFUSE_DATA, HVSP_READ_EFUSE_INSTR1);
      HVSP_read(0x00, HVSP_READ_EFUSE_INSTR2);
      read_efuse = HVSP_read(0x00, HVSP_READ_EFUSE_INSTR3);
#endif
    }
    else
    {

      // Get current fuse settings stored on target device
      read_lfuse = fuse_read(LFUSE_SEL);
      read_hfuse = fuse_read(HFUSE_SEL);
#if (BURN_EFUSE == 1)
      read_efuse = fuse_read(EFUSE_SEL);
#endif
    }

    // done, disable outputs

    // clear digital pins 0-7
    digitalWrite(DATA0, 0);
    digitalWrite(DATA1, 0);
    digitalWrite(DATA2, 0);
    digitalWrite(DATA3, 0);
    digitalWrite(DATA4, 0);
    digitalWrite(DATA5, 0);
    digitalWrite(DATA6, 0);
    digitalWrite(DATA7, 0);

    // set digital pins 0-7 as inputs for now
    pinMode(DATA0, INPUT);
    pinMode(DATA1, INPUT);
    pinMode(DATA2, INPUT);
    pinMode(DATA3, INPUT);
    pinMode(DATA4, INPUT);
    pinMode(DATA5, INPUT);
    pinMode(DATA6, INPUT);
    pinMode(DATA7, INPUT);

    digitalWrite(RST, HIGH); // exit programming mode
    delay(1);
    digitalWrite(OE, LOW);
    digitalWrite(WR, LOW);
    digitalWrite(PAGEL, LOW);
    digitalWrite(XA1, LOW);
    digitalWrite(XA0, LOW);
    digitalWrite(BS1, LOW);
    digitalWrite(BS2, LOW);
    digitalWrite(VCC, LOW);

    // Open serial port again to print fuse values
    Serial.begin(BAUD);
    delay(50);
    Serial.println();
    Serial.print(F("Read Low Fuse  "));
    Serial.print(F("hex: "));
    printHex(read_lfuse);
    Serial.print(F("  bin: "));
    printBits(read_lfuse);
    Serial.println();
    Serial.print(F("Read High Fuse "));
    Serial.print(F("hex: "));
    printHex(read_hfuse);
    Serial.print(F("  bin: "));
    printBits(read_hfuse);
    Serial.println();

#if (BURN_EFUSE == 1)
    Serial.print(F("Read Ext Fuse  "));
    Serial.print(F("hex: "));
    printHex(read_efuse);
    Serial.print(F("  bin: "));
    printBits(read_efuse);
    Serial.println();
#endif
    Serial.println();

    doNext = 1;
  } // end of doNext3 read sequence

  if (doNext == 4)
  { // 4=write fuses to target AVR

    // This business with TXC0 is required because Arduino doesn't give us a means to tell if a serial
    // transmission is complete before we move on and do other things.  If we don't wait for TXC0 to be reset,
    // I found that sometimes the 1st fuse burn would fail.  It turns out that DATA1 (which doubles as Arduino serial
    // TX) was still toggling by the time the 1st XTAL strobe latches the fuse program command.  Bad news.
#ifndef __AVR_ATmega32U4__
    UCSR0A |= _BV(TXC0); // Reset serial transmit complete flag (need to do this manually because TX interrupts aren't used by Arduino)
#endif
    Serial.println(F("Burning fuses"));
#ifndef __AVR_ATmega32U4__
    while (!(UCSR0A & _BV(TXC0)))
      ; // Wait for serial transmission to complete before burning fuses!
#endif
    Serial.end(); // We're done with serial comms (for now) so disable UART
    delay(50);
    // Initialize pins to enter programming mode

    // clear digital pins 0-7
    digitalWrite(DATA0, 0);
    digitalWrite(DATA1, 0);
    digitalWrite(DATA2, 0);
    digitalWrite(DATA3, 0);
    digitalWrite(DATA4, 0);
    digitalWrite(DATA5, 0);
    digitalWrite(DATA6, 0);
    digitalWrite(DATA7, 0);

    // set digital pins 0-7 as inputs for now
    pinMode(DATA0, INPUT);
    pinMode(DATA1, INPUT);
    pinMode(DATA2, INPUT);
    pinMode(DATA3, INPUT);
    pinMode(DATA4, INPUT);
    pinMode(DATA5, INPUT);
    pinMode(DATA6, INPUT);
    pinMode(DATA7, INPUT);

    digitalWrite(PAGEL, LOW);
    digitalWrite(XA1, LOW);
    digitalWrite(XA0, LOW);
    digitalWrite(BS1, LOW);
    digitalWrite(BS2, LOW);
    digitalWrite(WR, LOW); // ATtiny2313 needs this to be low to enter programming mode, ATmega doesn't care
    digitalWrite(OE, LOW);

    if (mode == HVSP)
    {
      digitalWrite(SDI, LOW); // set necessary pin values to enter programming mode
      digitalWrite(SII, LOW);
      pinMode(SDO, OUTPUT);   // SDO is same as RDY pin
      digitalWrite(SDO, LOW); // needs to be low to enter programming mode
    }

    // Enter programming mode
    digitalWrite(VCC, HIGH); // Apply VCC to start programming process
    delayMicroseconds(80);
    digitalWrite(RST, LOW); // Apply 12V to !RESET thru level shifter

    if (mode == HVSP)
    {
      // reset SDO after short delay, longer leads to logic contention because target sets SDO high after entering programming mode
      delayMicroseconds(1); // datasheet says 10us, 1us is needed to avoid drive contention on SDO
      pinMode(SDO, INPUT);  // set to input to avoid logic contention
    }

    delayMicroseconds(10); // Give lots of time for part to enter programming mode
    digitalWrite(OE, HIGH);
    digitalWrite(WR, HIGH); // Now that we're in programming mode we can disable !WR
    delay(1);

    // Now in programming mode until RST is set HIGH again to remove 12V

    // Now burn desired fuses
    // How we do this depends on which mode we're in
    if (mode == HVSP)
    {
      HVSP_write(HVSP_WRITE_LFUSE_DATA, HVSP_WRITE_LFUSE_INSTR1);
      HVSP_write(lfuse, HVSP_WRITE_LFUSE_INSTR2);
      HVSP_write(0x00, HVSP_WRITE_LFUSE_INSTR3);
      HVSP_write(0x00, HVSP_WRITE_LFUSE_INSTR4);
      while (digitalRead(SDO) == LOW)
        ; // wait until burn is done

      HVSP_write(HVSP_WRITE_HFUSE_DATA, HVSP_WRITE_HFUSE_INSTR1);
      HVSP_write(hfuse, HVSP_WRITE_HFUSE_INSTR2);
      HVSP_write(0x00, HVSP_WRITE_HFUSE_INSTR3);
      HVSP_write(0x00, HVSP_WRITE_HFUSE_INSTR4);
      while (digitalRead(SDO) == LOW)
        ;

#if (BURN_EFUSE == 1)
      HVSP_write(HVSP_WRITE_EFUSE_DATA, HVSP_WRITE_EFUSE_INSTR1);
      HVSP_write(efuse, HVSP_WRITE_EFUSE_INSTR2);
      HVSP_write(0x00, HVSP_WRITE_EFUSE_INSTR3);
      HVSP_write(0x00, HVSP_WRITE_EFUSE_INSTR4);
      while (digitalRead(SDO) == LOW)
        ;
#endif
    }
    else
    {
      //delay(10);

      // First, program HFUSE
      fuse_burn(hfuse, HFUSE_SEL);

      // Now, program LFUSE
      fuse_burn(lfuse, LFUSE_SEL);

#if (BURN_EFUSE == 1)
      // Lastly, program EFUSE
      fuse_burn(efuse, EFUSE_SEL);
#endif
    }

    Serial.begin(BAUD); // open serial port
    delay(50);
    Serial.println(); // flush out any garbage data on the link left over from programming
    Serial.println(F("Burn complete"));
    Serial.println();

    // done, disable outputs

    // clear digital pins 0-7
    digitalWrite(DATA0, 0);
    digitalWrite(DATA1, 0);
    digitalWrite(DATA2, 0);
    digitalWrite(DATA3, 0);
    digitalWrite(DATA4, 0);
    digitalWrite(DATA5, 0);
    digitalWrite(DATA6, 0);
    digitalWrite(DATA7, 0);

    // set digital pins 0-7 as inputs for now
    pinMode(DATA0, INPUT);
    pinMode(DATA1, INPUT);
    pinMode(DATA2, INPUT);
    pinMode(DATA3, INPUT);
    pinMode(DATA4, INPUT);
    pinMode(DATA5, INPUT);
    pinMode(DATA6, INPUT);
    pinMode(DATA7, INPUT);

    digitalWrite(RST, HIGH); // exit programming mode
    delay(1);
    digitalWrite(OE, LOW);
    digitalWrite(WR, LOW);
    digitalWrite(PAGEL, LOW);
    digitalWrite(XA1, LOW);
    digitalWrite(XA0, LOW);
    digitalWrite(BS1, LOW);
    digitalWrite(BS2, LOW);
    digitalWrite(VCC, LOW);

    doNext = 3; // read the fuses next
  }             //end of doNext4 read sequence

  // handle a string which came in via Serial and decide what to do next based on the input
  if (stringComplete)
  {
    evalString();
    if (inputString == "1")
    {
      Serial.println(F("ATMEGA mode"));
      PAGEL = PAGELM;
      BS2 = BS2M;
      mode = ATMEGA;
      doNext = 1;
      base = 99;
    }
    else if (inputString == "2")
    {
      Serial.println(F("ATtiny2313 mode"));
      // reassign PAGEL and BS2 to their combined counterparts on the '2313
      PAGEL = PAGELT;
      BS2 = BS2T;
      mode = TINY2313;
      doNext = 1;
      base = 99;
    }
    else if (inputString == "3")
    {
      Serial.println(F("ATtiny/HVSP mode"));
      PAGEL = PAGELM;
      BS2 = BS2M;
      mode = HVSP;
      doNext = 1;
      base = 99;
    }
    else if (inputString == "B")
    {
      Serial.println(F("Set Proposed Blank 328 Fuses"));
      lfuse = LFUSE;
      hfuse = HFUSE;
      efuse = EFUSE;
      doNext = 0;
      base = 99;
    }
    else if (inputString == "U")
    {
      Serial.println(F("Set Proposed Uno Fuses"));
      lfuse = 0xFF;
      hfuse = 0xDE;
      efuse = 0xFD;
      doNext = 0;
      base = 99;
    }
    else if (inputString.startsWith("L", 0))
    {
      Serial.print(F("Proposed Low Fuse  "));
      inputString = inputString.substring(1);
      evalString();
      if (base > 0)
      {
        lfuse = val1;
        doNext = 1;
      }
    }
    else if (inputString.startsWith("H", 0))
    {
      Serial.print(F("Proposed High Fuse "));
      inputString = inputString.substring(1);
      evalString();
      if (base > 0)
      {
        hfuse = val1;
        doNext = 1;
      }
    }
    else if (inputString.startsWith("X", 0))
    {
      Serial.print(F("Proposed Ext Fuse  "));
      inputString = inputString.substring(1);
      evalString();
      if (base > 0)
      {
        efuse = val1;
        doNext = 1;
      }
    }
    if (base > 0 && base < 20)
    {
      Serial.print(F("hex: "));
      printHex(val1);
      Serial.print(F("  bin: "));
      printBits(val1);
      Serial.println();
    }
    else if (base == 99)
      ; // print nothing
    else if (inputString == "W")
    {
      Serial.println(F("Write"));
      doNext = 4;
    }
    else if (inputString == "R")
    {
      Serial.println(F("Read"));
      doNext = 3;
    }
    else
    {
      Serial.println("Invalid input");
      doNext = 0;
    }
    // clear the string:
    inputString = "";
    stringComplete = false;
    base = 0;
  }

  // get new serial input and store in a String
  getSerialCharacters();

} //end of loop

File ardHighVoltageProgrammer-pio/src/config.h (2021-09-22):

#include <Arduino.h>

// User defined settings
#define DEFAULTMODE ATMEGA // If running in non-interactive mode, you need to set this to ATMEGA, TINY2313, or HVSP.
#define INTERACTIVE 1      // Set this to 0 to disable interactive mode
#define BURN_EFUSE 1       // Set this to 1 to enable burning extended fuse byte
#define BAUD 115200        // Serial port rate at which to talk to PC
#define SERIALTIMEOUT 3000 // Amount of time to wait for complete input if CR/LF off

// If interactive mode is off, these fuse settings are used instead of user prompted values
#define LFUSE 0x62 // default for ATmega328P per datasheet p282-284 0x62 UNO=0xFF
#define HFUSE 0xD9 // default for ATmega328P per datasheet p282-284 0xD9 UNO=0xDE Duemilanove328=0xDA
#define EFUSE 0xFF // default for ATmega328P per datasheet p282-284 0xFF UNO=0x05(effective FD)
// default low fuse  for ATtiny85 per datasheet p148-149 0x62 digispark=0xF1
// default high fuse for ATtiny85 per datasheet p148-149 0xDF digispark=0xD5
// default ext fuse  for ATtiny85 per datasheet p148-149 0xFF digispark=0xFE
// default low fuse  for ATtiny2313 per datasheet p159-160 0x64
// default high fuse for ATtiny2313 per datasheet p159-160 0xDF
// default ext fuse  for ATtiny2313 per datasheet p159-160 0xFF

// Pin Assignments
#define DATA0 A1
#define DATA1 1
#define DATA2 2
#define DATA3 3
#define DATA4 4
#define DATA5 5
#define DATA6 6
#define DATA7 7
#define VCC 12
#define RDY 13 // RDY/!BSY signal from target
#define OE 11
#define WR 10
#define BS1 A2
#define XA0 8
#define XA1 A4
#define RST A0 // 12V to target reset enable (!12V_EN)
#define XTAL1 A3
#define PAGELM A5
#define BS2M 9

// Pin assignment adjustments for Tiny
#define PAGELT BS1 // PAGEL is set to same pin as BS1 for ATtiny2313
#define BS2T XA1   // BS2 is set to same pin as XA1 for ATtiny2313
// Pin assignments for HVSP mode
#define SCI BS1
#define SDO RDY
#define SII XA0
#define SDI XA1

// Serial instructions for HVSP mode
// Based on the ATtiny85 datasheet Table 20-16 pg. 163-165.
// These instructions don't contain the necessary zero padding, which is added later.

// LFUSE
#define HVSP_READ_LFUSE_DATA B00000100   // For the commands we are interested in
#define HVSP_READ_LFUSE_INSTR1 B01001100 // only the 1st instruction contains a fixed data packet.
#define HVSP_READ_LFUSE_INSTR2 B01101000 // Instructions 2-3 have data = all zeros.
#define HVSP_READ_LFUSE_INSTR3 B01101100

#define HVSP_WRITE_LFUSE_DATA B01000000   // For the write instructions, the data contents
#define HVSP_WRITE_LFUSE_INSTR1 B01001100 // for instruction 2 are the desired fuse bits.
#define HVSP_WRITE_LFUSE_INSTR2 B00101100 // Instructions 3-4 have data = all zeros.
#define HVSP_WRITE_LFUSE_INSTR3 B01100100
#define HVSP_WRITE_LFUSE_INSTR4 B01101100

// HFUSE
#define HVSP_READ_HFUSE_DATA B00000100
#define HVSP_READ_HFUSE_INSTR1 B01001100
#define HVSP_READ_HFUSE_INSTR2 B01111010
#define HVSP_READ_HFUSE_INSTR3 B01111110

#define HVSP_WRITE_HFUSE_DATA B01000000
#define HVSP_WRITE_HFUSE_INSTR1 B01001100
#define HVSP_WRITE_HFUSE_INSTR2 B00101100
#define HVSP_WRITE_HFUSE_INSTR3 B01110100
#define HVSP_WRITE_HFUSE_INSTR4 B01111100

// EFUSE
// Note: not all ATtiny's have an EFUSE
#define HVSP_READ_EFUSE_DATA B00000100
#define HVSP_READ_EFUSE_INSTR1 B01001100
#define HVSP_READ_EFUSE_INSTR2 B01101010
#define HVSP_READ_EFUSE_INSTR3 B01101110

#define HVSP_WRITE_EFUSE_DATA B01000000
#define HVSP_WRITE_EFUSE_INSTR1 B01001100
#define HVSP_WRITE_EFUSE_INSTR2 B00101100
#define HVSP_WRITE_EFUSE_INSTR3 B01100110
#define HVSP_WRITE_EFUSE_INSTR4 B01101110

// Internal definitions
enum modelist
{
    ATMEGA,
    TINY2313,
    HVSP
};
enum fusesel
{
    LFUSE_SEL,
    HFUSE_SEL,
    EFUSE_SEL
};

// Global variables
byte mode = DEFAULTMODE;        // programming mode
String inputString = "";        // a string to hold incoming data
boolean stringComplete = false; // whether the string is complete
long val1;
byte base = 0;
byte lfuse = LFUSE;
byte hfuse = HFUSE;
byte efuse = EFUSE;

// These pin assignments change depending on which chip is being programmed,
// so they are put into variables
byte PAGEL = PAGELM;
byte BS2 = BS2M;

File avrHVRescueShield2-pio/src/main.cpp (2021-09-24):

/*
  Title:        HVRescue_Shield
  Description:  Arduino sketch for use with the HV Rescue Shield
  Author:       Jeff Keyzer
  Company:      MightyOhm Engineering
  Website:      http://mightyohm.com
  Contact:      http://mightyohm.com/blog/contact/  
  
  This sketch assumes that the Arduino is equipped with an AVR HV Rescue Shield.
  Schematics and other details are available at http://mightyohm.com/hvrescue2

  The sketch uses High Voltage Programming Mode to set fuses on many Atmel AVR family 8-bit microcontrollers.
  Version 2.0 adds support for High Voltage Serial Programming (HVSP) mode and 8-pin ATtiny devices, but remains
  backwards compatible with the 1.x series hardware.
  
  The HVPP routines are based on those described in the ATmega48/88/168 datasheet rev.
  2545M-AVR-09/07, pg. 290-297 and the ATtiny2313 datasheet rev. 2543I-AVR-04/06 pg. 165-176.  
  
  The HVSP routines are based on the ATtiny25/45/85 and 13A datasheets (ATtiny25/45/85 2586M–AVR–07/10 pg. 159-165,
  ATtiny13A 8126E-AVR-7/10 pg. 109-116).
  
  These routines are compatible with many other members of the AVR family that are not listed here.
  For a complete list of tested microcontrollers, see http://mightyohm.com/wiki/products:hvrescue:compatibility
  
  Changelog:
  3/15/11 2.12
    - New digital pin 0-7 (command&data) read/write routines for the Arduino Mega, since these lines are implemented
      differently on the Mega than on the original Arduino.
      
  3/8/11 2.11
    - Analog inputs (used here as digital outputs) are now called by their new Arduino A0-A5 names.
      
  2/2/11 2.1
    - adjusted RESET and VCC edge timing to work with new board design and avoid signal contention on SDO
    - fixed bug that prevented program from compiling in non-interactive mode
    - modified non-interactive mode so that read/verify serial comms still occur, but fuse values aren't prompted
  
  12/17/10 2.01
    - added missing braces to if(mode == HVSP) that sets SDO pinmode to INPUT
    - removed misleading comment about removing AVR when entering fuse values
    - default mode changed back to ATMEGA
  
  12/13/10 v2.0
    - Added support for 8-pin parts that use HV Serial Programming (HVSP)
    - New mode selection at startup determines which type of part is to be programmed 
    - Got rid of endSerial function, since Arduino now includes Serial.end (finally!)
    - Added a wait for serial transmit to complete before burning fuses.  Without this HFUSE burn would fail occasionally.
    - Numerous other minor tweaks, removal of unnecessary delays, better commenting
    
  9/24/10 v1.2a
    - ATtiny2313 mode was being set by default.  Changed default mode back to ATmega (see #define ATtiny).
    
  8/16/10 v1.2
    - Existing fuse settings are now shown before asking the user for new values
    - Added OE strobe after entering programming mode to get ATtiny2313 to read first fuse correctly.
    - Cleaned up code a bit
    - Some minor tweaks to data direction register settings during setup, etc.
    
  11/02/09 v1.1
    - Removed endSerial call after reading back fuse bytes, was spewing garbage into
      serial monitor
    - Still occasionally get garbage when opening serial monitor, not sure what is causing this.
    
  03/01/09 v1.0
    - ATtiny2313 support, enable with ATtiny option
    - 12V Step up converter enable is non-inverting, unlike previous level shifter circuit
    - added interactive mode, asks for fuse values to burn, option to turn off
    - added EFUSE support and option to enable
    - button now has very simple debounce routine
    
  09/24/08
    - original release of sketch "HVFuse" to support first implementation on perfboard
    - Details: http://mightyohm.com/blog/2008/09/arduino-based-avr-high-voltage-programmer/
  
  Copyright 2008, 2009, 2010 Jeff Keyzer
 
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
  You should have received a copy of the GNU General Public License
  along with this program.  If not, see <http://www.gnu.org/licenses/>.
*/

#include "config.h"
#include "modules.h"

void setup() { // run once, when the sketch starts

  byte response = NULL;  // user response from mode query
  
  // Set up control lines for HV parallel programming
  
  #if (MEGA == 0)  // Set up data lines on original Arduino
    PORTD = 0x00;  // clear digital pins 0-7
    DDRD = 0x00;  // set digital pins 0-7 as inputs for now
  #else  // Mega uses different ports for same pins, much more complicated setup.  yuck!
     mega_data_input();
  #endif
  
  pinMode(VCC, OUTPUT);
  pinMode(RDY, INPUT);
  pinMode(OE, OUTPUT);
  pinMode(WR, OUTPUT);
  pinMode(BS1, OUTPUT);
  pinMode(XA0, OUTPUT);
  pinMode(XA1, OUTPUT);
  pinMode(PAGEL, OUTPUT);
  pinMode(RST, OUTPUT);  // enable signal for DC-DC converter that generates +12V !RESET
  pinMode(BS2, OUTPUT);
  pinMode(XTAL1, OUTPUT);
  
  pinMode(BUTTON, INPUT);
  digitalWrite(BUTTON, HIGH);  // turn on internal pullup resistor

  // Initialize output pins as needed
  digitalWrite(RST, LOW);  // Turn off 12V step-up converter (non-inverting, unlike original circuit)
  digitalWrite(VCC, LOW); 

  Serial.begin(BAUD);  // Open serial port, this works on the Mega also because we are using serial port 0
  
    // Ask user which chip family we are programming
    #if ((ASKMODE == 1) && (INTERACTIVE == 1))
    Serial.println("Select mode:");
    Serial.println("1: ATmega (28-pin)");
    Serial.println("2: ATtiny2313");
    Serial.println("3: ATtiny (8-pin) / HVSP");
    
    while(response == NULL) {
      
      while (Serial.available() == 0);   // wait for character
      response = Serial.read();  // get response from user
    
      switch(response) {  // decide what to do
      case '1':
        mode = ATMEGA;
        break;
      case '2':
        mode = TINY2313;
        break;
      case '3':
        mode = HVSP;
        break;
      default:
        Serial.println("Invalid response.  Try again.");
        response = NULL;  // reset response so we go thru the while loop again
        break;
      } 
    }
    #endif
    
    // Report which mode was selected
    Serial.print("Selected mode: ");
    switch(mode) {
    case ATMEGA:
      Serial.println("ATMEGA");
      break;
    case TINY2313:
      Serial.println("ATtiny2313");
      // reassign PAGEL and BS2 to their combined counterparts on the '2313
      PAGEL = BS1;  
      BS2 = XA1;
      break;
    case HVSP:
      Serial.println("ATtiny/HVSP");
      break;
    }
}
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

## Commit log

2021-09-22 kicad start
    [ardHighVoltageProgrammer.sch]
2021-09-24 Sketch and cad
    [ardHighVoltageProgrammer.kicad_pcb, ardHighVoltageProgrammer.sch, avrHVRescueShield2.kicad_pcb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]
2021-10-07 schematics n pcb
    [avrHVRescueShield2.kicad_pcb, avrHVRescueShield2.sch]
2021-10-08 readme schematics
2022-06-03 new pcb
    [avrHVRescueShield2.kicad_pcb]
2022-10-01 error in schematics
    [avrHVRescueShield2.kicad_pcb, avrHVRescueShield2.kicad_sch]
2022-10-01 minor pcb change
    [avrHVRescueShield2.kicad_pcb]
2025-01-15 ISP Fuse Rescue added
    [ISP_Fuse_Rescue.kicad_pcb, ISP_Fuse_Rescue.kicad_sch, Logic.kicad_sch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]
2025-01-23 ISP Fuse Rescue
    [ISP_Fuse_Rescue.kicad_pcb, ISP_Fuse_Rescue.kicad_sch, Logic.kicad_sch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]
2025-01-26 kicad new versionj
    [HVRescue_Shield_r212.brd, HVRescue_Shield_r212.sch, HVRescue_Shield_r21_BOM.ods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]
2025-01-26 isp fuse rescue smd
    [ISP_Fuse_Rescue SMD.kicad_pcb, ISP_Fuse_Rescue SMD.kicad_sch, Logic.kicad_sch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]
2025-01-26 smd fuse rescue
    [ISP_Fuse_Rescue SMD.kicad_pcb, ISP_Fuse_Rescue SMD.kicad_sch, high_voltage.kicad_sch]

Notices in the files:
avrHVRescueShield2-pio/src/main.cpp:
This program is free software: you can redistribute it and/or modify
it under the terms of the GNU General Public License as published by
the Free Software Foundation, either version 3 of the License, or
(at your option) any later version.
